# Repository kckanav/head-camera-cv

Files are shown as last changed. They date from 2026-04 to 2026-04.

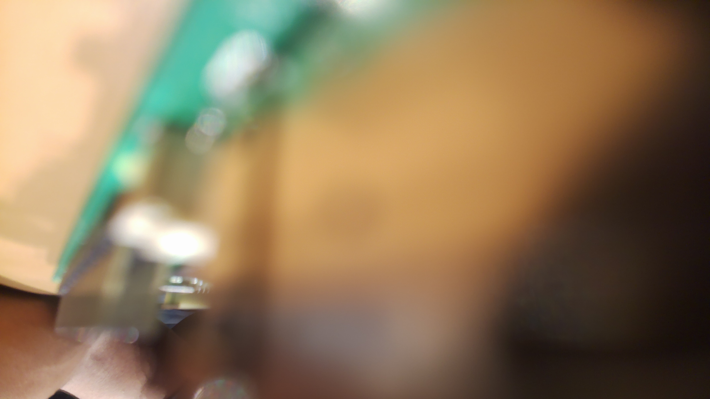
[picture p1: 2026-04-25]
inputs/23rd April 2026 - early test cam1.jpg

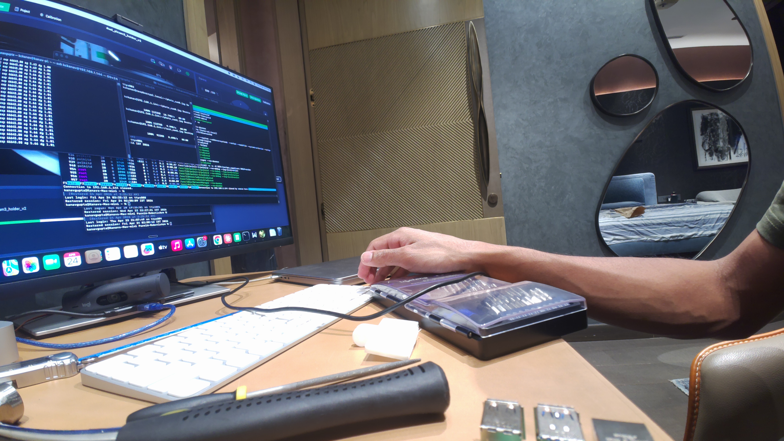
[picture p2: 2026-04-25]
inputs/24th April 2026 - photo cam1.jpg

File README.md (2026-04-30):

# Egocentric hand-and-object tracking on a head-mounted dual Pi Cam rig

## What we're building

A wearable computer-vision pipeline that captures the wearer's hands from their
own point of view and analyses **how they interact with objects** — finger
positions, arm pose, grip events, object orientation, and (eventually) the full
3D geometry of the interaction. Pure viewing first, neural-network analysis
later.

The key design choice is having **two cameras** instead of one. A single
egocentric camera can detect hands but has to *guess* depth from a flat image;
two cameras let us *measure* depth by triangulation. Most published egocentric
methods are monocular and have to work around that — we won't have to.

## Hardware

- 2× **Raspberry Pi Camera Module 3** (IMX708 sensor, 12 MP) mounted on a
  custom 3D-printed head bracket, tilted downward toward the wearer's hands.
- **Designed 24° toe-out** between the cameras (12° per side off-centre).
  Stereo calibration **recovered 18.9°** — print tolerances on the bracket.
  All math now uses the calibrated value, not the design value.
- **Recovered baseline**: 41.1 mm camera separation.
- **Raspberry Pi 5** for capture. Two sensor modes are exposed by the
  live-preview UI (`scripts/pi/dualstream.py`); both record at **1280×720
  H.264 at a hard-locked 30 fps**:
  - **2304×1296 binned full-FOV mode** — ~100° HFOV. **Current default**
    for the wide-FOV captures used by the WiLoR pipeline. Sensor caps at
    ~56 fps so 30 fps is comfortable.
  - **1536×864 centre-cropped mode** — ~75° HFOV. Older default; still
    used for the narrow-FOV reference clips and calibration.
  The 4608×2592 full-resolution mode is also offered by the UI but caps
  at ~14 fps so it can't sustain 30 fps recording — not used.
- Switching sensor mode changes intrinsics, so a fresh calibration is
  required after any switch. We keep both narrow-FOV (`""`) and wide-FOV
  (`" wide"`) calibrations side-by-side in `outputs/`.
- CAD source in `cad/dual_picam3_holder.scad`; v2 STL/3MF is the current revision.

## Pipeline plan (staged ladder)

The plan is to grow capability one stage at a time, validating each on real
footage before adding the next. Stages are roughly in order of "what unlocks
the most when you do it next":

| # | Stage | Purpose | Status |
|---|---|---|---|
| 1 | Per-camera hand keypoints (MediaPipe) | Prove fingers are trackable on real footage | **Done** |
| 2 | Arm / body pose | Wrist-elbow-shoulder context | Not started |
| 3 | Stereo calibration + rectification | Unlock metric depth for everything below | **Done** |
| 4 | Sparse 3D fingertip triangulation | Per-finger positions in centimetres | **Done** |
| 5 | Object segmentation / tracking (SAM 2) | Know which pixels belong to the object | **Next** |
| 6 | Grip event detection (heuristic first) | "Is the hand currently holding it?" | Not started |
| 7 | Object 6-DoF pose | Orientation, not just position | Optional / later |
| 8 | Dexterous hand capture (WiLoR + stereo) | Full MANO mesh + joint angles, robot-retargeting-ready | **In progress** — Phases 0-3 done, canonical pipeline at `scripts/pipeline/08_wilor_canonical.py`. Phase 4 (table-frame anchoring) and 5 (robot-training export) are next. See [PLAN.md](PLAN.md). |

## What we've achieved so far

### Stitching pipeline (`scripts/viz/stitch_panorama.py`)

Earlier the goal was to combine the two camera streams into one image. Started
as a Colab snippet (Lowe-less SIFT, Colab-only display, wrong-direction
homography); rewrote it to run locally with Lowe's ratio test, RANSAC, and
correct canvas math.

A homography is estimated **once** from a representative mid-clip frame and
reused for every frame — the cameras are rigidly mounted, so per-frame
estimation would be wasted compute. Output: `outputs/<date> - stitched
panorama.mp4` (~300 MB, gitignored; sample frame committed).

Important finding: **stitching is the wrong tool for our actual goal**.
A homography collapses both views onto a single plane, which destroys exactly
the parallax that gives depth perception. The panorama is useful as a quick
debug view, but for the real pipeline we want the two views *preserved*, not
fused. This is what motivates the stereo-calibration step over a fancier
stitcher.

### Hand detection sanity check (`scripts/pipeline/01_per_cam_sanity.py`)

Ran **MediaPipe HandLandmarker (Tasks API)** on a 15-second clip from each
camera (`1:40 – 1:55` of the 4-minute test recording).

Results on `25th April 2026` test clips:

| Camera | Frames | Hand-detected | Rate |
|---|---|---|---|
| cam0 | 451 | 449 | **99.6 %** |
| cam1 | 451 | 420 | **93.1 %** |

Inference runs at ~37 fps on M2 CPU — comfortably faster than real-time, so it
should work on the Pi 5 too.

#### Observations from the annotated outputs

- **Drop rate is ~2–3 % overall**, concentrated in moments where the hand is
  partially out of frame or only a few fingers (e.g. thumb + index + middle)
  are visible. The detector seems to either drop the hand or hallucinate a
  plausible-but-wrong skeleton in those frames. This is the expected failure
  mode for any 2D keypoint detector on partial views, and is one of the things
  stereo + 3D will help with.
- **Strong success case**: when the hand is wholly visible — even with heavy
  inter-finger occlusion (both hands gripping a tube of grease, fingers wrapped
  around) — keypoints stay locked at 0.94–0.99 confidence on both cameras.

### Stereo calibration (`scripts/calibration/make_charuco_board.py`, `scripts/calibration/calibrate_stereo.py`)

Stage 3 needed two pieces:

**1. A calibration target.** `make_charuco_board.py` generates a 9×6
ChArUco board PDF (30 mm squares, 22 mm 5×5 ArUco markers, A4 landscape @
600 DPI) with a 100 mm scale bar in the margin to verify print scale with a
ruler.

**2. The calibration itself.** `calibrate_stereo.py` takes synchronised left/right
videos of the board moved by hand in front of a tripod-mounted rig (~40 s of
footage at 30 fps), then:

- Samples one frame pair every 0.5 s (~80 pairs).
- Detects ChArUco corners independently in each view.
- Per-camera intrinsics with `cv2.calibrateCamera`.
- Stereo extrinsics with `cv2.stereoCalibrate(..., CALIB_FIX_INTRINSIC)`.
- Rectification with `cv2.stereoRectify(..., alpha=1)`. `alpha=1` preserves
  the full source FOV (with black padding where rectification has no source
  pixel) — important on this rig because hands frequently sit near the top
  edge of the frame; the more-aggressive `alpha=0` cropped them off.
- Saves intrinsics, extrinsics, rectification rotations, projection matrices,
  `Q`, and `cv2.remap` lookup tables to `outputs/<date> - stereo
  calibration.npz`. Renders a side-by-side rectified sample with green
  scanlines as a visual check (corresponding points must lie on the same
  scanline).

Result on `27th April 2026` calibration capture (71/79 usable pairs):

| Metric | Result | Bar |
|---|---|---|
| cam1 intrinsic rms | 0.24 px | < 0.5 = good |
| cam0 intrinsic rms | 0.27 px | < 0.5 = good |
| Stereo rms | 0.26 px | < 1.0 = good |
| Recovered toe-out | **18.9°** | designed 24° |
| Recovered baseline | **41.1 mm** | matches the bracket |
| Recovered focal length | fx ≈ 803 px | matches Pi Cam 3 ~75° HFOV |

Calibration is well below the conservative quality threshold; the rectified
sanity image (`outputs/<date> - rectified pair sanity.jpg`) confirms scanline
alignment across both views.

Implied **depth precision** at hand-interaction range (`ΔZ = Z² · Δd / (f · B)`,
½-px matching):

| Distance | Disparity | Depth precision |
|---|---|---|
| 30 cm | 110 px | ~1.4 mm |
| 50 cm | 66 px | ~3.8 mm |
| 80 cm | 41 px | ~10 mm |

Single-digit-millimetre depth resolution at hand-interaction range — plenty
for grip aperture, fingertip positions, and "is the hand touching the object"
heuristics.

### Sparse 3D hand triangulation (`scripts/pipeline/04_triangulate_mp.py`, `scripts/viz/inspect_3d_mp.py`)

Stage 4 puts everything together:

1. Load the stereo calibration `.npz`.
2. Rectify each frame pair with the precomputed `cv2.remap` tables.
3. Run MediaPipe HandLandmarker independently on each rectified view.
4. Pair left/right hand detections by **wrist-row proximity** — after
   rectification the epipolar constraint is "same image row", so a true
   match must agree in y. ±18 px tolerance.
5. Triangulate the 21 landmarks per paired hand with
   `cv2.triangulatePoints(P1, P2, ...)` → 3D positions in metres in the
   left-rectified camera frame.
6. **Sanity-filter** any pair whose triangulated wrist Z falls outside
   `[10 cm, 200 cm]` — catches wrong-hand pairings the row check lets through.
7. Sort hand slots by left-view wrist X for frame-to-frame stability.
8. Save per-frame `(N_frames, 2, 21, 3)` 3D landmarks (NaN-padded) to
   `outputs/<date> - stereo hand 3d.npz`.
9. Write a side-by-side rectified video annotated with skeletons, wrist
   depth (cm), and pinch (thumb-index) aperture (mm).

`inspect_3d_mp.py` is a small companion that loads the npz and plots wrist
depth and pinch over time, one curve per hand slot.

Result on the first 60 s of the test recording (alpha=1 rectification):

| Metric | Result |
|---|---|
| Hands detected (cam1) | 1689 / 1801 = 94 % |
| Hands detected (cam0) | 1582 / 1801 = 88 % |
| Stereo-paired (after Z filter) | 1100 / 1801 = 61 % |
| Median wrist depth | 33.3 cm |
| Wrist depth 5–95 pct | 21.6 – 47.0 cm |
| Median pinch aperture | 36 mm |
| Inference rate | ~19 fps on M2 CPU (two MediaPipe instances) |

The 5–95 percentile wrist-depth band lies entirely within the expected
hand-interaction range. The trajectory plot shows clean steady-state
clustering at ~32 cm during periods of close manipulation, with both hands
tracked simultaneously.

**Known residual issue.** A single fingertip can occasionally triangulate
to a wildly wrong Z even when the wrist is solid — MediaPipe's per-finger
keypoints are noisier than the wrist, and a 1 px disparity error at that
landmark gives a large depth error. Visible as occasional pinch outliers
> 150 mm in the trajectory plot. Per-landmark Z-clamping or short-window
temporal smoothing would clean it up. Not blocking.

### Stage 8 in progress — WiLoR + stereo dexterous hand pipeline (`scripts/pipeline/08_wilor_canonical.py`)

The sparse 21-keypoint MediaPipe output is enough for *trajectories* but not
for retargeting to arbitrary robot grippers. To capture data that can drive
a parallel-jaw, 3-finger, or anthropomorphic robot hand from the same
recording, we moved to **WiLoR** ([CVPR 2025](https://github.com/rolpotamias/WiLoR)) —
an end-to-end ViT model that produces full **MANO** parameters (16 joint
rotations + 778-vertex mesh) per hand. Stereo gives us an unusual
advantage: WiLoR is monocular and has scale ambiguity, but our calibrated
stereo can fix the scale precisely.

Phases 0–3 are all done:

- **Phase 0–1** (env + sanity): WiLoR runs on Apple MPS on this M2 host
  (with the YOLO detector on CPU per ultralytics issue #4031). Sanity
  check on a real Pi-Cam frame: hand detected, mesh extent ~16 cm, 2D
  keypoints overlay cleanly on the actual hand.
  Entry point: `scripts/experiments/wilor_sanity.py`.
- **Phase 2** (per-view WiLoR + stereo wrist triangulation): metric wrist
  depth annotations on a side-by-side video. Median wrist depth ~34 cm,
  in line with what MediaPipe-stereo reported on similar footage
  (regression baseline holds).
  Entry point: `scripts/experiments/wilor_wrist_stereo.py`.
- **Phase 3 (full Umeyama)** — *reference experiment*: triangulate all 21
  keypoints, fit a 7-DOF similarity transform, project the same world-
  frame mesh into both views. 99.3% fuse rate, but median 2D reprojection
  error blew up to 10 px. **Worse than monocular WiLoR.** Kept for the
  negative-result record.
  Entry point: `scripts/experiments/wilor_phase3_umeyama.py`.
- **Phase 3 (anchored)** — *canonical pipeline*: per view, `cv2.solvePnP`
  fits 6-DOF pose to WiLoR's 2D keypoints; stereo wrist depth supplies
  a 1-DOF metric scale anchor `k = Z_stereo / t_pnp[2]`. Uniform 3D
  scaling preserves perspective 2D projection (`(X,Y,Z) → (fX/Z, fY/Z)`
  is invariant under `(kX, kY, kZ)`), so the rendered overlay matches
  the per-view monocular baseline (median PnP residual ~2 px) while
  the underlying mesh is metric. The scale anchor uses stereo only for
  the one thing it can give that monocular cannot.
  Entry point: `scripts/pipeline/08_wilor_canonical.py`. Has full
  CUDA/MPS device portability via `scripts/_lib/device.py` plus a
  `--bench` flag for per-stage perf tracing.

Discovered and fixed along the way:

- **Left-hand keypoint mirroring**: WiLoR's `ViTDetDataset` flips left-hand
  input crops, so `pred_keypoints_2d` and `pred_vertices` come out in
  flipped-crop coords. Multiplying X by −1 before mapping back to image
  coords fixes anatomically-flipped renders.
- **Centralised WiLoR runtime workarounds** in `scripts/_lib/wilor_setup.py`:
  pyrender stub (no EGL on macOS), `torch.load weights_only=False` patch
  (PyTorch 2.6 broke YOLO ckpt loading), and the wilor sys.path / chdir
  setup. Every wilor script now has a single `import wilor_setup` line
  instead of 60+ lines of boilerplate.

Full plan, install gotchas, and Phases 4–5 (visualisation + table-frame
robot-training export) are in [`PLAN.md`](PLAN.md).

### Other known limitations

- **Handedness labels are unreliable** on egocentric video. MediaPipe was
  trained primarily on selfie/forward-facing data, so its `Left` / `Right`
  classification can flip on top-down head-mount input. The keypoint
  *positions* themselves are fine; we side-step handedness by pairing hands
  across views via the rectified-row epipolar constraint instead. Cheap fix
  if we ever need it: relabel based on which side of the frame the wrist
  sits on. Proper fix: swap in **HaMeR** or **WiLoR** (both trained on
  egocentric datasets like Ego4D and EPIC-Kitchens) — that's stage 8.
- **Parallax artefacts in the stitched panorama** — close-foreground hands
  sit at a different depth than background and can't be aligned by a single
  planar homography. Inherent to the geometry, not a bug. Going away
  because we're not stitching anymore — the calibrated stereo pipeline
  preserves both views.

## Repo layout

```
README.md / PLAN.md / CLAUDE.md   Docs (read CLAUDE.md before contributing).

scripts/                          All pipeline entry points (run from repo root).
  _lib/                           Shared imports (sys.path-injected by each script).
    dated.py                      today_pretty() helper.
    device.py                     pick_device / configure_perf — CUDA/MPS/CPU portability.
    wilor_setup.py                pyrender stubs, torch.load patch, wilor sys.path/chdir.
  pi/
    dualstream.py                 Pi-side dual capture + live HTML preview UI.
  calibration/
    make_charuco_board.py         ChArUco PDF generator (stereo calibration target).
    make_aruco_marker.py          ArUco PDF generator (table-frame anchor for stage 8 phase 4-5).
    calibrate_stereo.py           Stereo calibration from board videos (stage 3).
  pipeline/                       The canonical pipeline, in run order.
    01_per_cam_sanity.py          MediaPipe HandLandmarker per-camera sanity (stage 1).
    04_triangulate_mp.py          Sparse 3D hand triangulation via MediaPipe + stereo (stage 4).
    08_wilor_canonical.py         WiLoR + stereo metric depth (stage 8). --bench for perf trace.
  viz/                            Visualisation + debug viewers.
    play_stereo.py                SBS rectified playback with on-the-fly --alpha.
    depth_dense.py                Dense stereo depth (overlay / turbo / both).
    inspect_3d_mp.py              Trajectory plot of triangulated MediaPipe hand data.
    stitch_panorama.py            Old SIFT/RANSAC panorama stitcher (debug-only).
    wilor_ar_monocular.py         Per-view monocular AR overlay (visual baseline).
  experiments/                    Reference scripts kept for the record.
    wilor_sanity.py               Single-image WiLoR sanity check (stage 8 phase 1).
    wilor_wrist_stereo.py         Per-view WiLoR + stereo wrist-only triangulation (phase 2).
    wilor_phase3_umeyama.py       Phase 3 (full Umeyama) — superseded; kept as negative-result record.

cad/                              Head-mount CAD (.scad source + .stl / .3mf exports).
inputs/                           Tracked test material — filenames dated by capture.
outputs/                          Tracked generated artefacts — filenames dated by generation.

raw/                              (gitignored) Raw camera mp4 + h264 streams from the Pi.
models/                           (gitignored) Re-downloadable model weights (e.g. hand_landmarker.task).
wilor/                            (gitignored) Cloned WiLoR repo — large weights, separate license.
.venv/                            (gitignored) Python 3.9 venv for stages 1-4.
.venv-hamer/                      (gitignored) Python 3.10 venv for stage 8.
```

Run scripts from the repo root so the relative paths in `inputs/` /
`outputs/` / `models/` resolve correctly:
`.venv/bin/python scripts/calibration/calibrate_stereo.py` or
`.venv-hamer/bin/python scripts/pipeline/08_wilor_canonical.py`.

Filenames in `inputs/` and `outputs/` look like `27th April 2026 - stereo
hands annotated.mp4`. Re-running a script on a new day produces a new
dated artefact rather than overwriting yesterday's, so progress is visually
browsable from `ls outputs/`.

**Not in git** (over GitHub's 100 MB limit, redownloadable, or
license-restricted; kept locally only): everything in `raw/`, `models/`,
`wilor/`, and the full stitched panorama / 60-s WiLoR demo renders in
`outputs/`. Switch to **git-lfs** if any of these need to be tracked.

## What's next

Stages 3 and 4 are done — we now have calibrated stereo and a working sparse
3D hand pipeline. Two reasonable directions:

**Stage 5 — object segmentation (SAM 2).** Identify which pixels belong to
the held object so we can ask "which finger is touching what part of it?".
Combines naturally with the existing 3D hand keypoints to produce per-frame
hand–object contact features.

**Refine stage 4.** Per-landmark Z-clamping and short-window temporal
smoothing to clean up the fingertip outliers; identity tracking so hand
slots stay consistent when hands physically cross; running MediaPipe on the
*raw* frames and projecting the keypoints through the rectification map
afterward, to claw back the small detection-rate gap from running on
rectified frames.

## Commit history (running log)

- `c9810b2` — initial object detection from both different cameras
- `5301032` — organise repo into inputs/ and outputs/ with readable dated filenames
- `02fef54` — README summarising goals, architecture, status, and next step
- `e63edb9` — hand detection on first minute of each camera
- `e008189` — generate ChArUco calibration board sized for the Pi Cam 3 rig
- `fa40c85` — stereo calibration (stage 3): script, capture footage, recovered geometry
- `402af8c` — sparse 3D hand triangulation (st	age 4): pipeline, results, trajectory plot
- `19c7ecd` — README + CLAUDE.md update for stages 3 and 4
- `9f17555` — stage 8 phase 0+1 (WiLoR setup + sanity)
- `5254d62` — stage 8 phase 2 + minimal phase 3 (per-view WiLoR + stereo wrist triangulation, with left-hand mirror bug fix)
- `d22400f` — stage 8 wide-FOV: dualstream sensor-mode UI, recalibration, demo CLI args, 60-s perf trace
- `582a596` — restructure root into scripts/ + cad/ + raw/ + models/ for navigability

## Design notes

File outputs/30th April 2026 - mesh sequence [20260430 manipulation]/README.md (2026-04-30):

# Mesh sequence — 20260430 manipulation

Generated by `scripts/viz/export_obj_sequence.py` from
`30th April 2026 - dataset [20260430 manipulation].npz`.

## Contents

- `scene.obj` — static helper: 1 m × 1 m table plane at Z=0, plus a 8 cm
  marker outline at the origin. Import once for visual context.
- `mesh_NNNN.obj` (542 frames at 30.0 fps, ~18.1 s) — per-frame
  hand meshes. Each file contains up to two named objects:
  `hand_slot0` (the leftmost-by-X hand in the source video) and `hand_slot1`.
  Frames where a hand wasn't tracked simply omit that object.

Hand meshes follow MANO topology: 778 vertices, 1538 triangles per hand.

## Coordinate frame

**Table frame, metric metres.** (0, 0, 0) is the marker centre on the
table. +Z is up from the table surface. Set your DCC tool's scene units
to metres.

## Open in Blender

### Easiest — Stop Motion OBJ addon

1. Install the [Stop Motion OBJ](https://github.com/neverhood311/Stop-motion-OBJ)
   addon (free, in the Blender extension menu or downloadable from GitHub).
2. File → Import → Mesh Sequence...
3. Point at this directory, set the file pattern to `mesh_*.obj`, and
   set the playback frame rate to **30 fps**.
4. Import `scene.obj` separately (File → Import → Wavefront (.obj)) for
   the table + marker reference.

### Manual via Python (no addon)

Paste into Blender's Python console:

```python
import bpy
from pathlib import Path

seq_dir = Path("/absolute/path/to/this/directory")
for f in sorted(seq_dir.glob("mesh_*.obj")):
    bpy.ops.wm.obj_import(filepath=str(f))

# Then keyframe visibility per frame manually, or animate via the
# Mesh Cache modifier on a base mesh.
```

## Animation timing

Frame `mesh_NNNN.obj` corresponds to time `NNNN / 30` seconds since the
start of the source clip.

Set the scene render fps to **30** to play back at real-time speed.

## What's where

The hand meshes are oriented anatomically: looking down at the table
from above, with +Z pointing up at the camera. The marker on the table
is at (0, 0, 0). Hand positions on the table appear in the +X / +Y
plane (approximately; the marker's chirality defines the +X axis of the
table).

This is the **K-anchored metric mesh** from the canonical pipeline —
positions are stereo-correct (the wrist is metric), but the mesh size is
uniformly scaled by the per-frame `k ≈ 0.78` factor so the wrist matches
stereo. To get the WiLoR-monocular-sized mesh instead (slightly larger),
rebuild from `mano_pose` + `mano_betas` in the parent `.npz` via the
MANO model, then translate by `wrist_table[i, slot]`.

## Provenance

- `schema_version`: 1.0
- `source_canonical`: 30th April 2026 - phase3 anchored fused [20260430 manipulation].npz
- `source_anchor`: 30th April 2026 - table anchor [20260430 manipulation].npz
- `source_calibration`: 30th April 2026 wide - stereo calibration.npz
- `generated_on`: 30th April 2026

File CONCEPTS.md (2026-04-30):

# Pipeline concepts (Q&A)

Notes on **how** and **why** the egocentric hand-tracking pipeline works,
captured from a series of explainer questions during development. Read this
if you want to understand the conceptual framework — what each model does,
what units and frames the data lives in, and why the pipeline is structured
the way it is.

For **what** the scripts do, see [`CLAUDE.md`](CLAUDE.md).
For **what's planned**, see [`PLAN.md`](PLAN.md).
For the **project narrative + ladder**, see [`README.md`](README.md).

---

## Contents

1. [What CV models are we using? (full data flow + math)](#1-what-cv-models-are-we-using)
2. [What creates the blue-glove effect?](#2-what-creates-the-blue-glove-effect)
3. [MANO vs WiLoR — what is the difference?](#3-mano-vs-wilor--what-is-the-difference)
4. [How are θ and β stored, and in what reference frame?](#4-how-are-θ-and-β-stored-and-in-what-reference-frame)
5. [What is the ArUco marker for?](#5-what-is-the-aruco-marker-for)
6. [Why don't we just triangulate the table directly?](#6-why-dont-we-just-triangulate-the-table-directly)

---

## 1. What CV models are we using?

Three deep-learned models, plus a stack of OpenCV geometry. None of the
deep-learned ones live inside this repo — they're either downloaded
checkpoints or installed packages.

### The deep-learned models

**YOLOv8 hand detector** (`wilor/pretrained_models/detector.pt`)
- Input: full RGB frame.
- Output: 2D bounding boxes of hands + handedness label (left/right).
- Math: standard one-stage anchor-free detector. CNN backbone → per-pixel
  bbox + class.

**WiLoR ViT** (`wilor/pretrained_models/wilor_final.ckpt`)
- Input: a 256×256 hand crop from YOLO's bbox.
- Output: MANO pose θ (16 axis-angle joint rotations), shape β (10
  betas), per-image weak-perspective camera, plus reprojected 2D / 3D
  keypoints and the 778-vertex mesh.
- Math: ViT encoder → transformer decoder → regression heads. Trained on a
  mix of monocular hand datasets. The output is **monocular and
  scale-ambiguous** — pose and *relative* shape are right, but absolute
  size is a guess.

**MANO** (`wilor/mano_data/MANO_RIGHT.pkl`)
- Not a learned step at runtime — a fixed parametric hand model.
- Input: pose θ + shape β.
- Output: 778-vertex mesh + 21 joint positions.
- Math: linear blend skinning on a mean template mesh, plus pose-dependent
  blend shapes. Closed form, fast.

### OpenCV geometry (no deep learning, just math)

**ArUco / ChArUco detectors** — `cv2.aruco.ArucoDetector` finds quadrilateral
fiducials and returns their 4 corners with sub-pixel precision. Used for
calibration (ChArUco board) and table anchoring (single ArUco marker).

**Stereo calibration suite** (one-time, captured in our `.npz`):
- `cv2.calibrateCamera` → intrinsics K (focal length, principal point) and
  distortion coefficients per camera.
- `cv2.stereoCalibrate` → extrinsic R, T relating the two cameras:
  `X_right = R · X_left + T`.
- `cv2.stereoRectify` → rectification rotations R1, R2 + projection
  matrices P1, P2 such that, after virtually rotating each camera by
  R1/R2, corresponding image points lie on the same row.

**Stereo triangulation** — `cv2.triangulatePoints(P1, P2, x_l, x_r)` solves
for 3D X such that both rectified projections match. After rectification:
`Z = fx · baseline / (x_l − x_r)`.

**PnP** — `cv2.solvePnP` / `solvePnPGeneric`. Given 3D object points in
some local frame and their 2D image projections, recover the camera pose
`(R, t)` such that `K · (R · X_local + t)` projects to the observed 2D.
We use SQPNP for hand keypoints and IPPE_SQUARE for the marker.

**MediaPipe HandLandmarker** (legacy, only in
`scripts/pipeline/04_triangulate_mp.py`) — fast 21-keypoint detector kept
as a regression baseline against WiLoR.

### Data flow per frame

```
                                    ┌──── cam1 RAW frame (left) ────┐
                                    │                               │
[1] YOLO ──► hand bboxes  ─────────►│                               │
                                    │                               │
[2] WiLoR ViT (per crop) ──► θ, β, kp_3d_local, kp_2d_full, vertices│
                                    │                               │
[3] MANO (θ, β) ──► 778-vertex mesh in MANO local frame             │
                                    │                               │
                                    │       ┌──── cam0 RAW frame (right) ───┐
                                    │       │                                │
[1+2+3] same pipeline on right view │       │   another (R_right, t_right)   │
                                    │       │                                │
                                    ▼       ▼                                │
                          ┌────────────────────────────────────┐             │
[6] Triangulate wrist:    │ wrist 2D in cam1 + wrist 2D in cam0│             │
    rectify both, then    │ ──► cv2.triangulatePoints          │             │
    triangulate           │ ──► metric Z_wrist in WORLD frame  │             │
                          └────────────────────────────────────┘             │
                                       │                                     │
                                       ▼                                     │
[7] solvePnP(SQPNP) per view: fit (R_view, t_view) so monocular mesh         │
    projects to WiLoR's 2D keypoints. t_view[2] = monocular wrist depth.     │
                                       │                                     │
                                       ▼                                     │
[8] Scale anchor: k = Z_stereo_wrist / t_view[2]   (1 DOF per view)          │
                                       │                                     │
                                       ▼                                     │
[9] Metric mesh in cam frame: k · (R_view · vertices_local + t_view)         │
                                       │                                     │
                          ┌────────────┴───────────┐                         │
                          │                        │                         │
                   ┌──────▼─────┐         ┌────────▼──────┐                  │
                   │ project to │         │ transform via │                  │
                   │ each view  │         │ R1.T into     │                  │
                   │ (render)   │         │ WORLD frame   │                  │
                   └────────────┘         │  (stored)     │                  │
                                          └───────────────┘                  │

    ┌────────────────────────────────────────────────────────────────────────┘
    │  Separately:
    │  [4] ArUco detector finds marker corners in each view
    │  [7] solvePnP(IPPE_SQUARE) → marker pose (R_l, t_l) per view
    │  ──► T_world_to_table per frame (transforms WORLD frame → TABLE frame)
    │
    ▼
For Phase 5 export: apply T_world_to_table to all stored 3D quantities,
producing table-anchored, metric, retargeting-ready demonstrations.
```

### The two non-obvious tricks

**Trick 1 — Uniform 3D scaling preserves perspective 2D.** A point at
`(X, Y, Z)` projects to `(fX/Z, fY/Z)`. Scale the *whole 3D point* to
`(kX, kY, kZ)` and the projection is `(fkX/kZ, fkY/kZ)` = unchanged. So we
can change the metric size of the monocular mesh without breaking its 2D
fit. That's why a **1-DOF stereo correction** (just absolute scale) is
enough — pose, rotation, and finger-shape are all preserved from monocular.

**Trick 2 — Disparity → depth.** After rectification, the only thing that
varies for a 3D point is its horizontal pixel position between the two
views. The relationship is exactly `Z = fx · baseline / disparity`. So
with calibrated `fx ≈ 545 px` and `baseline = 41.9 mm`, every pixel of
disparity error at 50 cm depth costs ~1 cm in Z. That's the noise floor
we live with on this rig.

---

## 2. What creates the blue-glove effect?

The blue glove is the rendered **MANO mesh** painted onto the original
frame in 2D, with shading. Five steps:

**1. Mesh geometry — what we render.** MANO gives us 778 vertices and 1538
triangular faces forming a hand. WiLoR predicts the per-frame mesh; the
canonical pipeline scales it to metric size via the `k` anchor.

**2. Project 3D vertices to 2D.** `cv2.projectPoints(vertices_3d_camera,
K, dist)` gives us the 2D pixel coordinates for each of the 778 vertices
in the image plane. Now each triangle has both a 3D position (in camera
frame) and a 2D footprint.

**3. Paint the triangles back-to-front.** This is the **painter's
algorithm** — we sort all 1538 triangles by their **mean 3D Z** (depth),
descending, and draw the farther ones first so nearer ones overpaint
them. No z-buffer, no GPU — just sort and fill in order.

```python
face_z = triangles_3d.mean(axis=1)[:, 2]
order = np.argsort(-face_z)           # back to front
for fi in order:
    cv2.fillConvexPoly(overlay, pts2[fi], color)
```

**4. Per-triangle shading — Lambertian blue.** This is what gives it the
3D look instead of being a flat blob. For each triangle:
- Compute its 3D normal: `n = (v1 − v0) × (v2 − v0)`, normalised.
- Compute brightness:
  `shade = max(|n · light_direction|, 0.3)`.
  We use a fixed light direction `(0, −0.4, −1)` (slightly above and
  behind the camera) and clamp to 0.3 minimum so back-facing triangles
  aren't fully black.
- Multiply the base BGR colour `(255, 110, 30)` by `shade`. That base
  is the saturated cyan-blue you see.
- Draw the triangle's edge with a slightly darker BGR `(220, 80, 20)`.
  That gives the polygonal "wireframe-on-skin" look.

**5. Alpha-blend onto the original frame.**

```python
out = cv2.addWeighted(overlay, 0.55, original_frame, 0.45, 0)
```

55% mesh-colour, 45% original. That's why the hand still shows through
faintly — the glove is translucent rather than opaque.

### Why it looks "right"

Because the underlying mesh is positioned to **match WiLoR's 2D keypoints
exactly** (uniform-scaling preserves 2D projection — Trick 1 above). So
when WiLoR locks the wrist and finger positions to the actual hand pixels,
the mesh you paint over the frame is registered to within ~2 px of the
real hand outline. Combined with depth-sorted shading, your eye reads it
as a 3D blue glove sitting on the hand instead of a flat overlay.

Pure NumPy + OpenCV — no GPU rendering. ~15 ms per frame on Apple MPS
for one hand.

---

## 3. MANO vs WiLoR — what is the difference?

The short version: **MANO is a *mathematical model* of a hand. WiLoR is a
*neural network* that estimates the parameters of that model from an
image.** They live at completely different levels of the stack — one is
geometry, one is perception.

### MANO — the hand "puppet"

MANO was published by the Max Planck Institute in 2017. It's a fixed
mathematical formula that describes how a hand looks and articulates.
Think of it as a rigged 3D hand model in Blender — fixed mesh topology
and fixed skeleton. You give it inputs and it gives you a 3D mesh.

Inputs:
- **θ** (theta): 16 joints × 3 axis-angle values = 48 numbers describing
  the joint rotations (wrist, knuckles, finger curls).
- **β** (beta): 10 shape coefficients describing the *person*'s hand
  (size, finger thickness, etc.). These don't change frame-to-frame for
  the same person.

Output (deterministic, computed by a closed-form function):
- A **778-vertex mesh** (the surface).
- **21 keypoints** (anatomical landmarks: wrist, MCPs, PIPs, DIPs,
  fingertips).

That's it. MANO is the puppet — it can take any pose, but it doesn't
know how to look at the world. It's frozen on disk as `MANO_RIGHT.pkl`.

### WiLoR — the "puppeteer"

WiLoR is a neural network (a Vision Transformer) trained on lots of hand
images. Its job is to look at a hand crop and **predict θ and β** —
i.e., decide what pose the MANO puppet should be in to match the image.

- Input: a 256×256 RGB hand crop.
- Output: predicted θ and β (plus a few extras like a per-image
  weak-perspective camera).

WiLoR by itself doesn't produce a mesh — it produces *parameters*. The
mesh comes out only when you plug those parameters into MANO's formula.

### How they work together

```
   image ─► [WiLoR network] ─► θ, β ─► [MANO formula] ─► 778-vertex mesh + 21 joints
            (perception)              (geometry)
```

Inside WiLoR's checkpoint there's actually a copy of MANO baked in, so
calling `model(batch)` runs both steps in one forward pass and gives you
`pred_vertices`, `pred_keypoints_3d`, etc. directly. But conceptually
they're separate.

### What this means for our pipeline specifically

- **The skeleton drawn on the AR video** = the 21 keypoints. The
  *anatomy* (which dot is the wrist, which is the index-MCP, etc.) is
  **defined by MANO**. Their *positions in the image* come from
  **WiLoR's predictions**.
- **The blue-glove mesh** = the 778-vertex surface. The *topology*
  (which vertex connects to which) is **MANO**. Their *3D positions*
  come from **WiLoR + MANO**.

In the saved `.npz`, the most compact and most "lingua franca" thing to
keep is **θ and β**. With those, anyone can rebuild the mesh later by
calling MANO. Mesh vertices are 778 × 3 = 2334 floats per hand per frame;
θ + β is just 48 + 10 = 58 floats. Most robot-retargeting codebases
consume θ directly — they map MANO's joint angles onto their robot's
joint angles.

### Why the distinction matters

It means we have a **swappable perception layer**. If WiLoR ever becomes
obsolete (or HaMeR works better on egocentric video, or some new model
lands later), we can swap the predictor without changing anything
downstream — as long as the new model also outputs MANO parameters, all
our anchoring math, our table-frame export, our retargeting code keeps
working.

That's why our Phase 5 export should save `mano_pose` (= θ) and
`mano_betas` (= β) — not just the meshes. The meshes are derived; θ + β
are the *source of truth*.

---

## 4. How are θ and β stored, and in what reference frame?

### θ — joint rotations

Stored as a `(16, 3)` float array. **48 numbers.**

Each row is an **axis-angle vector**: a 3D vector where the *direction*
is the rotation axis and the *magnitude* (in **radians**) is the
rotation angle. So if `θ[5] = (0, 0, 1.57)`, that means "joint 5 rotates
1.57 radians (= 90°) around the +Z axis of its parent joint's frame."

There are 16 joints in MANO's tree: 1 wrist + 3 per finger × 5 fingers.
They're arranged hierarchically (wrist → MCP → PIP → DIP), so each
rotation is **relative to its parent**. The wrist's rotation is relative
to the MANO "root frame" — i.e., it tells you which way the whole hand
is facing in MANO's local universe.

Units: radians. Range: ~[−π, π] per axis.

### β — shape coefficients

Stored as a `(10,)` float array. **10 numbers.**

These are **PCA scores** in a learned basis of hand shapes. MANO was
built by scanning ~1000 real hands and running PCA on the variation. β
= (1.5, −0.3, 0.8, ...) means "this person's hand = mean hand + 1.5 ×
shape_basis_0 − 0.3 × shape_basis_1 + ...". The first component is
roughly overall size (big hand vs small hand); later ones capture
finger-length ratios, palm thickness, etc.

Units: dimensionless. Typical range: [−3, +3] (it's standardised).

### 3D vertex positions — units and frame

When MANO computes its mesh from (θ, β), the output is `(778, 3)`
floats. The units are **metres**. But — and this is the key — they're in
**MANO's local frame, not the camera frame, and not the world**.

What does that mean concretely?

- The wrist is at the origin `(0, 0, 0)` of MANO's local frame.
- The mesh extends roughly ±0.1 m around the wrist (a hand is ~10 cm
  across).
- The orientation is a "canonical hand orientation" defined by MANO —
  palm-down, fingers pointing along some axis.

So when you call `MANO(θ, β)` and look at vertex 100, you might get
something like `(0.04, −0.02, 0.07)` metres. That doesn't mean "vertex
100 is 4 cm to the right of the camera." It means "vertex 100 is 4 cm
in the +X direction from the wrist *in MANO's own coordinate system*,
when the hand is posed according to θ".

It's analogous to having a rigged 3D hand model in Blender: the mesh has
positions in the model's local space, but until you put it INTO a scene
with a transform, those positions don't correspond to any real-world
location.

### Why this matters for our pipeline

WiLoR outputs vertices in MANO's local frame. To **place that mesh in
your real scene** (above your table, anchored to the marker), we need
three additional pieces of information that MANO+WiLoR alone can't give
us:

1. **Where is the hand in 3D space?** (translation `t`)
2. **Which way is the hand facing in 3D space?** (rotation `R`)
3. **What's the absolute size?** (scale `k`)

Each of those is solved by a different step in the canonical pipeline:

| Question | Solved by | Math |
|---|---|---|
| Where in 3D? | `solvePnP` per view | Fit (R, t) so projected MANO 2D matches image 2D, plus stereo wrist for absolute Z |
| Which way facing? | Same `solvePnP` | The R part of (R, t) |
| Absolute size? | Stereo wrist depth + the `k` anchor | `k = Z_stereo_wrist / t_pnp[2]` |

Once you have (R, t, k), you transform every MANO vertex:

```
vertex_in_camera = k · (R · vertex_in_MANO_local + t)
```

Now the vertex has a 3D position in the camera's frame, in metric metres.

Then `T_world_to_table @ vertex_in_world` puts it in table frame.

So the **chain of frames** for a single vertex looks like:

```
MANO local frame (wrist-centred, MANO units)
    │  scale by k, rotate by R, translate by t   ← from solvePnP + stereo anchor
    ▼
Real left camera frame (metres, camera origin)
    │  apply R1 (stereo rectification)            ← from cv2.stereoRectify
    ▼
World frame (= rectified-left frame, metres)
    │  apply T_world_to_table                     ← from ArUco solvePnP
    ▼
Table frame (metres, marker centre = origin, Z = up)
```

That's why the saved `.npz` has so many fields — each is needed to
express where something is at a different stage of the chain.

### Pixels vs 3D positions

MANO outputs are **never** in pixels. Pixels show up only when you
*project* a 3D point through a camera intrinsic matrix `K`:

```
pixel = K · (3D point in camera frame)
```

That's the `cv2.projectPoints` step. It's the LAST thing that happens
in the canonical pipeline — only for the rendered visualisation.

For a Phase 5 export to a 3D modelling software, **you don't want pixels
at all**. You want the 3D vertex positions in **table frame, in metric
metres**. Or even more compact: you want θ + β + the wrist 6-DoF
transform that maps MANO local → table frame, which lets the consumer
rebuild everything else.

---

## 5. What is the ArUco marker for?

The marker is doing a **different job** than answering the three "where /
which-way / how-big" questions for the hand. Those three are answered
**entirely from the cameras**, not the marker:

- **Where the hand is in 3D space** → `solvePnP` per view + stereo
  triangulation of the wrist.
- **Which way the hand is facing** → `solvePnP` per view (the R part of
  the same fit).
- **Absolute size (the `k` anchor)** → stereo triangulation of the wrist
  2D landmark across both views, which gives metric Z, which lets us
  compute `k = Z_stereo / Z_monocular`.

None of these involve the marker. They use:
- The **stereo calibration** (the `.npz` from `calibrate_stereo.py`),
  which tells us the rigid geometry between the two cameras — that's
  what makes stereo triangulation possible at all.
- The **monocular WiLoR predictions** in each image.

So after this stage, we have a metric MANO mesh **in the moving
head-mounted camera's frame**, frame by frame.

### What the marker does — answers a different question

The marker answers: **"Where is the table?"**

Without the marker: your camera is on your head. As your head moves, the
camera frame moves with it. A point that's stationary on the table — say,
the corner of a coaster — has different camera-frame coordinates every
frame. If we just exported the hand mesh in camera frame, you'd see the
hand AND the entire world wobbling around in Blender as you replayed the
demo, because everything is being expressed relative to a moving camera.

For robot training, you want everything in **the robot's workspace** —
which is anchored to the table, not to the user's head. So we need a
transform that takes camera-frame points → table-frame points, **per
frame**, accounting for head motion.

The marker provides exactly this. Detected every frame, `solvePnP` against
its known size gives us `T_world_to_table[frame]` — a per-frame transform
from the moving world (rectified-left) frame into the stationary table
frame.

The marker doesn't help us figure out where the hand is. It helps us
**express** where the hand is, **relative to the stationary table** instead
of the moving camera.

### The two stereo roles, separated

There are actually **two completely separate uses of stereo** in our
pipeline, and it's worth keeping them distinct:

| Stereo role | Source | What it gives us |
|---|---|---|
| **Stereo calibration** (one-time, from the ChArUco board capture) | `<date> wide - stereo calibration.npz` | The rigid geometry between cam1 and cam0 (their R, T, intrinsics, distortion). This is what lets us triangulate ANY 2D-2D point pair into 3D. |
| **Stereo triangulation** (per frame, for the wrist) | Live, in `08_wilor_canonical.py` | The metric Z of the wrist, which anchors the absolute scale of the monocular MANO mesh via `k`. |

The marker is **separate from both of these**. It's a third role:

| Marker role | Source | What it gives us |
|---|---|---|
| **Table anchoring** (per frame) | Live, in `09_anchor_table.py` | A per-frame `T_world_to_table` transform that takes any camera-frame point and re-expresses it in stationary table coordinates. |

The full chain for a single hand vertex on a single frame is:

1. WiLoR predicts MANO θ, β → 778 vertices in **MANO local frame**
   (scale-free, wrist-centred).
2. `solvePnP` + stereo wrist triangulation → vertex in **left camera
   frame** (metric metres, but in a frame that moves with the head).
3. Stereo calibration's `R1` rotates left-camera into rectified-left =
   **world frame** (still moves with head, but parallel-rectified).
4. Marker-derived `T_world_to_table` → vertex in **table frame** (metric
   metres, stationary, Z=0 is the table surface).

The first three steps don't involve the marker at all. The marker only
enters at step 4.

---

## 6. Why don't we just triangulate the table directly?

You could absolutely triangulate the table. Two reasons we use a marker
anyway, both worth understanding.

### Reason 1 — Identifying the "same point" in both views

Stereo triangulation only works when you know that pixel `(x_l, y_l)`
in the left view and pixel `(x_r, y_r)` in the right view are **the
same physical point in 3D**. For the wrist, this is easy: WiLoR detects
"the wrist landmark" in each view independently, and we trust those two
detections refer to the same anatomical wrist.

For the table, what's the equivalent? The table is **mostly
featureless**. Most of its surface is flat colour with no texture. If you
tried to match pixels between the two views — say "this beige pixel in
the left view = which beige pixel in the right view?" — you'd have no
way to know. Every beige pixel looks like every other beige pixel. The
matching is ambiguous.

This is the classic **correspondence problem** in stereo vision. It's
why dense stereo (the `viz/depth_dense.py` script) gives crisp depth on
textured regions but noisy/missing depth on flat surfaces. If you ran
SGBM on a clip of just your bare table, you'd get a depth map full of
speckle and holes precisely on the table.

The marker solves this brutally well: the high-contrast black-and-white
pattern is uniquely identifiable, and the corner detector finds the same
four corners reliably in both views with sub-pixel precision.

### Reason 2 — A point isn't enough; you need a frame

Even if we DID triangulate the table successfully (let's say you put a
textured tablecloth on it and stereo SGBM works perfectly), we'd recover
the **table plane** — its height and orientation, but **not its in-plane
axes**.

A plane has 3 DOF: one for height, two for tilt. A coordinate frame has
6 DOF: 3 for translation, 3 for rotation. So the missing piece is the
**rotation about the table normal** — i.e., which direction along the
table is "X" and which is "Y"?

Without that, you'd have:
- table-Z (height) for any point. ✓
- table-X and table-Y. ✗

Robot retargeting needs all 6 DOF. "The mug is at table position (12 cm,
5 cm)" requires knowing what 12 cm in X means.

The ArUco marker is **chiral** — its pattern is asymmetric, so its X and
Y axes are well-defined. Detecting the marker gives you all 6 DOF of
the table frame in one shot.

### Alternatives if you ever want to drop the marker

You're not stuck with a marker. There are real alternatives that recover
the full 6-DOF frame:

1. **Texture the table.** A patterned tablecloth or a coffee table with
   strong wood grain gives stereo enough features to triangulate the
   surface. Fit a plane to the triangulated points → get the plane. Then
   orient it using one strong feature (a logo, a corner of an object,
   the edge of the table) → get X/Y. Sensitive to lighting and surface
   texture.

2. **Track the table edges.** If the camera can see the corners or edges
   of the table, those are strong geometric features. You can
   triangulate the corners, fit a rectangle, and use the rectangle's
   sides for X and Y. Practical only if your FOV reliably includes the
   edges.

3. **Multiple markers / objects.** Put two distinguishable objects on
   the table at known positions. Each gives a 3D point; the line between
   them gives you an X axis; the table normal completes the frame. Less
   robust than one well-detected ArUco.

4. **A larger fiducial like a ChArUco board** (which you already have
   for calibration). Same idea as our marker but with more redundancy.

5. **Detect a known object** (mug with a known shape, fixed known
   pattern). Conceptually fine but requires a prior 3D model and
   pose-estimation infrastructure.

The single ArUco we're using is essentially the *minimum-overhead*
version of these. It's small (8 cm), trivially detected, gives all 6
DOF, and only needs to be visible in one view to anchor that frame for
that frame.

### The deeper answer

**Stereo can recover the table's plane, but not its frame.** The
marker's job is to define the **frame**, not to provide depth. The
marker isn't a stereo input at all — it's a 6-DOF reference object.

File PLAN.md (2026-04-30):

# Plan: dexterous hand capture via WiLoR + stereo

> **Pick-up-where-we-left-off (read this first if starting a new session):**
>
> - Repo state: stages 1, 3, 4 of the main pipeline are committed (MediaPipe per-camera, stereo calibration, sparse 3D triangulation). See `README.md` for the full picture.
> - Stage 8 status: **Phases 0, 1, 2, minimal Phase 3, full Phase 3, and Phase 3 (anchored) all done.**
> - **Phase 3 (anchored) is the canonical pipeline.** Per view: PnP fits a 6-DOF pose to WiLoR's 2D keypoints; stereo wrist depth supplies a 1-DOF metric scale anchor `k = Z_stereo / t_pnp[2]`. Uniform 3D scaling preserves 2D projection, so the rendered overlay matches `scripts/viz/wilor_ar_monocular.py` (median PnP residual ~2 px) while the underlying mesh is metric.
> - **Phase 3 (full Umeyama)** is kept as a reference experiment. It re-fit the mesh as a global 7-DOF rigid transform — gave one mesh in one frame, but median 2D reprojection error blew up to 10 px (with a 27 px tail), worse than monocular WiLoR. The negative result is committed for posterity.
> - Verify the env still works at any time (run from repo root):
>     ```bash
>     .venv-hamer/bin/python scripts/experiments/wilor_sanity.py             # single image, fast
>     .venv-hamer/bin/python scripts/experiments/wilor_wrist_stereo.py       # 15-s clip, ~7 min on MPS
>     .venv-hamer/bin/python scripts/viz/wilor_ar_monocular.py               # per-view monocular AR (10-s wide clip)
>     .venv-hamer/bin/python scripts/experiments/wilor_phase3_umeyama.py     # full Umeyama fusion (reference experiment)
>     .venv-hamer/bin/python scripts/pipeline/08_wilor_canonical.py          # canonical: monocular pose + stereo depth
>     .venv-hamer/bin/python scripts/pipeline/08_wilor_canonical.py --bench  # adds per-stage perf trace
>     ```
>   `wilor_sanity.py` should print `device: mps  yolo: cpu`, detect 1 hand, pop open the overlay.
>   `08_wilor_canonical.py` runs through 300 frames at ~1 fps on warm MPS and pops open the SBS annotated video at the end.
> - **Device portability**: all wilor scripts use `_lib/device.py` (`pick_device()` / `configure_perf()`). Same script behaves correctly on macOS+MPS, Linux+CUDA (with fp16 ViT, TF32, multi-worker DataLoader), and CPU-only. On a fresh CUDA box, expect ~3–5× lower per-frame inference time vs MPS.
> - The WiLoR repo lives at `wilor/` (gitignored — large weights, separate license). If you re-clone it, follow the Phase 0 commands further down. The MANO models live at `wilor/models/MANO_{RIGHT,LEFT}.pkl` (you uploaded them) and are symlinked from `wilor/mano_data/` where the WiLoR config expects them. **Note:** WiLoR only ever loads `MANO_RIGHT.pkl` and uses the standard mirror trick for left hands — `MANO_LEFT.pkl` is symlinked but unused.
> - Tracked entry points: `pipeline/08_wilor_canonical.py` (canonical), `viz/wilor_ar_monocular.py` (visual baseline), `experiments/wilor_sanity.py`, `experiments/wilor_wrist_stereo.py`, `experiments/wilor_phase3_umeyama.py` (reference experiments).
> - Last run results live at `outputs/<date> - wilor sanity *`, `outputs/<date> - wilor stereo demo *`, `outputs/<date> - wilor ar overlay *`, `outputs/<date> - phase3 fused *`, `outputs/<date> - phase3 anchored *`.

---

Status as of `27 April 2026`: stages 1, 3, 4 of the README ladder are done
(MediaPipe per-camera, stereo calibration, sparse 3D triangulation). This
plan covers the next push — replacing MediaPipe with a MANO-producing model
(WiLoR primary, HaMeR fallback) so the captured dataset is rich enough to
retarget to *any* gripper.

## Why

The captured dataset is for **robot-manipulation imitation learning**. The
robot may eventually use a parallel-jaw gripper, a 3-finger gripper, or an
anthropomorphic hand — the dataset must be **richer than any specific
gripper** so retargeting code can project it onto whatever robot is being
trained.

Concretely that means we need, per-frame, per-hand:

- **MANO joint angles** — `(16, 3)` axis-angle, the canonical retargeting target
- **MANO mesh vertices** — `(778, 3)` metric, needed for hand-object contact
- **Wrist 6DoF** — translation + rotation in the world frame, from stereo
- **Hand-presence flag** — per slot, whether the estimate is trustworthy

MediaPipe gives 21 sparse keypoints per hand; downstream code would have to
fit MANO to those points anyway, with extra error. So we go directly to a
MANO-producing model.

## Model choice: WiLoR primary, HaMeR fallback

| | WiLoR | HaMeR |
|---|---|---|
| Source | https://github.com/rolpotamias/WiLoR (CVPR 2025) | https://github.com/geopavlakos/hamer (CVPR 2024) |
| Detector | Built-in fully-convolutional, no external dep | detectron2-based |
| MPS-compatibility on M2 | Likely fine (no detectron2) | detectron2 has no MPS support — would force CPU detection |
| Reported speed | Detection >130 fps (M / S variants); reconstruction is ViT-based | ~6 fps total on consumer GPU |
| Output | MANO params + mesh | MANO params + mesh |
| Robotics-literature usage | Newer, less | More established (DexCap, Bunny-VisionPro reference HaMeR) |

WiLoR wins on **ease of setup on this Mac** and on **inference speed**. Both
produce the same MANO output, so swap-cost is low if WiLoR has issues on our
egocentric-top-down distribution.

## Why our stereo gives us an unusual advantage

Both WiLoR and HaMeR are **monocular** by default — they predict pose +
shape but **absolute scale is ambiguous** (a small hand close vs a big hand
far look identical to a single camera). With our calibrated stereo we can
fix scale: triangulate stable landmarks (wrist, palm-base, middle-finger
MCP) from the two views, then rescale the monocular MANO output to match.
This is a stronger setup than the default literature pipeline gets.

## Phased plan (each phase independently testable)

### Phase 0 — environment & weights
- New venv: `.venv-hamer/` (separate from `.venv` to avoid PyTorch ↔ MediaPipe
  dep conflicts). Name kept generic so it's reusable if we swap WiLoR for
  HaMeR later.
- Clone repo: `git clone https://github.com/rolpotamias/WiLoR wilor/` into
  the project root (subdir, gitignored).
- Install: torch (with MPS), the wilor package, smplx, and whatever the
  upstream `setup.py` / `pyproject.toml` lists.
- Download WiLoR checkpoints via the upstream script.
- **User-required step**: register at `mano.is.tue.mpg.de`, download
  `MANO_RIGHT.pkl`, place at `wilor/mano_data/MANO_RIGHT.pkl` (path per
  upstream README).
- Validate: WiLoR demo runs on a stock sample image, produces a mesh.

### Phase 1 — single-frame, single-view sanity *(done)*
- Entry point: `scripts/experiments/wilor_sanity.py`.
- Runs YOLO (CPU — known MPS bug for Pose models) + WiLoR (MPS) on
  `inputs/24th April 2026 - photo cam0.jpg`. Outputs an OpenCV overlay
  (`outputs/<date> - wilor sanity overlay.jpg`) and the MANO mesh as a
  plain `.obj` (`outputs/<date> - wilor sanity hand0.obj`).
- **Result on the test capture (4608×2592):**
  - YOLO detected 1 hand correctly, labelled "right" (correct vs. MediaPipe
    which couldn't reliably get handedness on egocentric data — promising
    sign for our use case).
  - WiLoR mesh extent ~16.3 cm in MANO local frame — anatomically plausible.
  - 21 reprojected 2D keypoints land on the actual hand in the overlay.
  - Inference: YOLO 0.4 s on CPU; WiLoR 6.3 s on MPS for the *first* call
    (kernel compilation overhead). Sustained per-frame cost in Phase 2 will
    be much lower — we'll measure properly there.
- Pyrender doesn't load on macOS without OSMesa, so the sanity script stubs
  the three renderer-using submodules of `wilor.utils`. Inference works;
  visualisation will need a separate path in Phase 4 (probably trimesh or
  matplotlib).

### Phase 2 + minimal Phase 3 — per-view WiLoR with stereo wrist triangulation *(done as one combined demo)*
- Entry point: `scripts/experiments/wilor_wrist_stereo.py`. Default clip is the 15-s grease
  clip with the wide-FOV calibration; `--long` switches to the 60-s narrow
  clip preset. CLI args `--clip-left/--clip-right/--calib/--tag/--max-frames`
  override paths and limits — relative paths resolve against the repo root.
- Per frame pair:
  1. YOLO detect on the raw left + right frame (CPU; ultralytics MPS bug).
  2. WiLoR forward pass per detected hand per view (MPS, ~0.9 s warm).
  3. Project each hand's wrist 2D into rectified space via
     `cv2.undistortPoints(..., R=R1|R2, P=P1|P2)`.
  4. Match left/right hand detections by rectified wrist-row proximity
     (`ROW_TOL_PX = 30`).
  5. Triangulate matched wrists with `cv2.triangulatePoints(P1, P2, ...)` →
     metric wrist 3D in the left rectified camera frame.
  6. Sanity-filter wrist Z to `[5 cm, 200 cm]`. (5 cm not 10 — on a head-mount
     hands genuinely get this close when manipulating something near the face.)
  7. Annotate the SBS frame with the WiLoR skeleton, bbox, handedness label,
     and the metric `z=XX.X cm` if pairing succeeded.
- Output:
  - `outputs/<date> - wilor stereo demo {tag}.mp4` — SBS annotated video.
  - `outputs/<date> - wilor stereo demo {tag}.npz` — per-frame
    `wrist_3d_metric[N, 2, 3]`, `keypoints_2d_left/right[N, 2, 21, 2]`,
    `handedness[N, 2]`.

**Result on the 15-s grease clip (451 frames, 7.5 min wall time):**
- Inference 0.98 s/frame on warm MPS.
- Wrist depth (cm): median 34.1, 5–95 [6.5, 40.1], min 5.1, max 69.7.
- Median lines up well with what MediaPipe-stereo reported on similar
  footage (~33 cm), giving us a regression baseline.

**Why this is "minimal" Phase 3 and what's still ahead:**
- Only the wrist landmark is triangulated. The full Phase 3 (next section)
  triangulates all 21 landmarks and fits the entire MANO mesh into the
  shared world frame.

### Phase 3 (full Umeyama) — reference experiment *(done, kept for comparison)*

**Status.** Built and run on the wide 10-s clip; 596/600 pairs fused (99.3%);
median 2D reprojection error 10/11 px (left/right) with a 27 px tail.
**Worse than monocular WiLoR by every visual metric.** Replaced as the
canonical pipeline by Phase 3 (anchored) below — the negative result is
kept here so future-you (and future-readers) understands why the simpler
1-DOF anchor is preferred over the 7-DOF Umeyama refit.

**Why it was worse.** The 7-DOF (s, R, t) re-fit gave us cross-view 3D
consistency (one mesh, not two) at the cost of breaking WiLoR's per-view
2D accuracy. Triangulation noise on fingertips at the 41 mm baseline
propagates into the global rigid transform; weighted Umeyama mitigates
but doesn't eliminate it. The lesson: don't fight the model. WiLoR was
trained for monocular 2D + relative 3D and is excellent at that — only
add what stereo can give that monocular cannot, which is absolute scale.

**Goal (as designed).** For each frame and each detected hand, produce
*one* MANO mesh in the rectified-left camera frame at metric scale,
consistent with both views' WiLoR predictions.

**The core unknowns per matched hand per frame: a similarity transform
(s, R, t) — 7 DOF.** That places WiLoR's MANO output (in its own root-
centered local frame) into the rectified-left camera frame. WiLoR's pose θ
and shape β stay as predicted for the first iteration; β refinement is
Phase 3.5.

**Algorithm — two steps, the second is optional:**

1. **Umeyama (closed-form)** — triangulate all 21 keypoints to get 21 metric
   3D points; solve `Σᵢ wᵢ ‖triangulated_3d[i] − (s·R·pred_kp3d_local[i] + t)‖²`
   via SVD (Umeyama 1991, weighted variant). Closed form, no iteration.
2. **Levenberg–Marquardt (refinement, Phase 3.4)** — minimize 2D reprojection
   error across both views over `(s, axis_angle_R, t)` with a robust loss.
   Initialize from step 1.

**Phased implementation. Each substep is independently testable.**

| Substep | What | Status |
|---|---|---|
| 3.1 | Triangulate all 21 keypoints per matched hand. Per-keypoint validity = (rectified-row agreement < 8 px) & (Z plausible). | in progress |
| 3.2 | Weighted Umeyama. Down-weight fingertips (1 px disparity → big depth error at 41 mm baseline). Apply `(s, R, t)` to all 778 vertices. | in progress |
| 3.3 | Project the world-frame mesh into both unrectified views via `R1.T` (undo rectification) + `cv2.projectPoints` with `K_l/K_r, dist_l/dist_r`. Render with the same painter's-algorithm code as `scripts/viz/wilor_ar_monocular.py`. | in progress |
| 3.4 | LM refinement of `(s, R, t)` against 2D reprojection error in both views. `scipy.optimize.least_squares` with `loss="soft_l1"`. | deferred |
| 3.5 | Joint solve over `(s, β, R, t)` — adds shape refinement. Stereo identifies β; monocular β is ill-posed. | deferred |
| 3.6 | Sequence smoothing. Belongs in Phase 4 if jitter is bothersome. | deferred |

**File plan.** Single entry point: `scripts/experiments/wilor_phase3_umeyama.py` (was `wilor_phase3.py` before the reorg). Outputs:

- `outputs/<date> - phase3 fused [<tag>].npz` — schema below.
- `outputs/<date> - phase3 ar overlay [<tag>].mp4` — SBS, fused mesh
  rendered into both **unrectified** frames so it's directly comparable to
  the per-view monocular `scripts/viz/wilor_ar_monocular.py` output.

**Output schema (`.npz`):**

```
verts_3d_world      (N, 2, 778, 3)  float32 — world (= rectified-left) frame, NaN where missing
kp_3d_world         (N, 2,  21, 3)  float32 — triangulated, per-keypoint NaN where invalid
kp_valid            (N, 2,  21)     bool    — row-tolerance + Z-bound mask
placement_s         (N, 2)          float32 — Umeyama scale
placement_R         (N, 2,  3, 3)   float32 — Umeyama rotation
placement_t         (N, 2,  3)      float32 — Umeyama translation
umeyama_residual_m  (N, 2)          float32 — mean residual after fit, metres
reproj_err_left_px  (N, 2)          float32 — median 2D error of fused mesh keypoints in left
reproj_err_right_px (N, 2)          float32 — same for right
handedness          (N, 2)                  — strings
fps, image_size, calib_path                   self-contained for downstream code
```

**Validation (what makes 3.1–3.3 a "success"):**

1. **Reprojection error.** Median < 5 px after Umeyama in both views; > 10 px
   means coordinate-frame mismatch or wrong-hand pairing.
2. **Wrist agreement.** Fused mesh's wrist position matches the directly-
   triangulated wrist (minimal Phase 3) to within 1 mm — same point, two
   ways.
3. **Visual.** Fused-mesh AR overlay video shows fingertips landing on the
   same physical fingertip in both views (which is *not* reliable in
   `scripts/viz/wilor_ar_monocular.py`'s independent per-view meshes).

**Risks and mitigations:**

- *Fingertip triangulation noise* — weighted Umeyama (palm joints heavier).
- *Cross-view chirality flip* (left view sees "right hand", right view sees
  "left hand" for the same physical hand) — known issue, document for now,
  fix by relabeling chirality based on rectified wrist X position.
- *Outlier hand pairings* — if Umeyama residual > 2 cm, fall back to wrist-
  only fusion (the minimal Phase 3 result) and flag the frame.
- *WiLoR's `pred_keypoints_3d` frame convention* — assumed root-centered
  MANO local. Will verify at runtime by checking `kp3d[0] ≈ 0`.

### Phase 3 (anchored) — monocular pose + stereo metric depth *(canonical)*

**Goal.** Same as Phase 3 (full): produce a metric MANO mesh per matched-hand
pair. **But solve only what stereo can uniquely give: absolute scale.**
Trust WiLoR's monocular fit for everything else.

**Algorithm.** Per matched-hand pair, per view:

1. WiLoR forward pass — `pred_vertices` (778, 3 in MANO local frame),
   `pred_keypoints_3d` (21, 3 same frame, root-centered),
   `pred_keypoints_2d_full` (21, 2 in real-image pixels).
2. **`cv2.solvePnP(SQPNP)`** — fit (R_view, t_view) such that
   `K · (R_view·X_local + t_view)` projects to WiLoR's 2D keypoints.
   t_view[2] is WiLoR's monocular wrist depth estimate in the real
   camera frame.
3. **Stereo triangulate the wrist** in rectified-left frame, then transform
   into each real camera frame to get `Z_stereo_view`.
4. **Scalar scale anchor**: `k_view = Z_stereo_view / t_view[2]`. (1 DOF.)
5. **Metric mesh**: `mesh_metric_view = k_view · (R_view · verts_local + t_view)`,
   in each real camera frame. Render via `cv2.projectPoints` through
   (K_view, dist_view).

**Why this works (math).** *Uniform 3D scaling preserves perspective 2D
projection.* `(X, Y, Z) → (fX/Z, fY/Z)`; scale to `(kX, kY, kZ)` →
`(fkX/kZ, fkY/kZ)` = same 2D. So we can change the metric size of the
mesh without breaking WiLoR's pixel-perfect 2D fit. Stereo gives us
exactly one piece of information that monocular cannot: absolute scale.
We use it for that, and only that.

**Result on the wide 10-s clip:**
- 596/600 pairs anchored (99.3%, same as Phase 3 full).
- **Median 2D reprojection ~2 px** (5–95 [0.9, 6 px]) — visually
  indistinguishable from `scripts/viz/wilor_ar_monocular.py`.
- Wrist depth median 45.9 cm — agrees with Phase 3 (full) exactly
  (both pipelines triangulate the same wrist).
- Per-view scale `k` typically agrees within ~3% (k_L ≈ k_R per frame),
  which is the genuine cross-view sanity check: stereo is giving us a
  consistent metric size, not just a depth.

**Output schema (`.npz`):**

```
verts_3d_world           (N, 2, 778, 3)  metric MANO mesh in rectified-left frame,
                                          derived from LEFT view (canonical), NaN where missing
wrist_3d_world           (N, 2, 3)       stereo-triangulated wrist
pose_R_left              (N, 2, 3, 3)    PnP rotation in original-left cam frame
pose_t_left              (N, 2, 3)       PnP translation in original-left cam frame
pose_R_right             (N, 2, 3, 3)    PnP rotation in original-right cam frame
pose_t_right             (N, 2, 3)       PnP translation in original-right cam frame
scale_k_left             (N, 2)          1-DOF anchor for left view
scale_k_right            (N, 2)          1-DOF anchor for right view
pnp_residual_left_px     (N, 2)          PnP fit quality
pnp_residual_right_px    (N, 2)          PnP fit quality
handedness               (N, 2)          strings
fps, image_size, calib_path                self-contained
```

**Trade-offs vs Phase 3 (full):**

| | Phase 3 (full Umeyama) | Phase 3 (anchored) |
|---|---|---|
| 2D pixel accuracy | poor (10–27 px) | excellent (1–2 px) |
| Metric depth | yes | yes |
| Cross-view 3D agreement | yes by construction (one mesh) | partial — wrists agree, rest may drift slightly |
| DOF solved with stereo | 7 (s, R, t) | **1 (s only)** |
| Sensitivity to fingertip triangulation | high | very low (only wrist matters) |

For the dataset we're producing (Phase 5 — robot-training export), the
canonical 3D representation is `verts_3d_world` from the anchored
output. The anchored mesh in left-cam frame transformed to world
(rectified-left) frame is what downstream retargeting code consumes.

### Phase 4 — visualization & validation
- Side-by-side rectified video with mesh overlay (extends `triangulate.py`'s
  output style).
- Trajectory plots: wrist 6DoF over time, per-finger flexion over time
  (extends `scripts/viz/inspect_3d_mp.py`).
- Sanity bounds: mesh volume in physically plausible range; joint angles
  inside MANO's training distribution.
- Cross-check: wrist trajectory should agree with the existing
  MediaPipe-stereo `.npz` from stage 4 to within a few mm. Disagreement is a
  flag.

### Phase 5 — robot-training export
- Final dataset format (`outputs/<date> - manipulation dataset.npz` or `.h5`):
  - `mano_pose[N, 2, 16, 3]`
  - `mano_betas[N, 2, 10]`
  - `vertices[N, 2, 778, 3]` metric, world frame
  - `wrist_6dof[N, 2, 6]` translation + axis-angle rotation
  - `hand_present[N, 2]` boolean
  - `timestamps[N]`
  - `intrinsics`, `extrinsics` (copied from calibration `.npz` for self-containment)
- Schema documented inline so retargeting code can consume without
  reverse-engineering.

## Where existing code fits

| Existing | Role going forward |
|---|---|
| `scripts/pi/dualstream.py` | Pi-side capture, unchanged |
| `scripts/calibration/make_charuco_board.py`, `scripts/calibration/calibrate_stereo.py` | Provide the calibration `.npz` that fixes stereo scale — unchanged |
| `scripts/calibration/make_aruco_marker.py` | Generates the table-anchor fiducial PDF (Phase 4–5 prep) |
| `scripts/pipeline/04_triangulate_mp.py` (MediaPipe stereo) | Kept as **fast preview path** (~37 fps) and as a **regression baseline** — wrist trajectories should agree with WiLoR-stereo |
| `scripts/experiments/wilor_wrist_stereo.py` | The **Phase 2** reference (wrist-only stereo). Kept as the regression baseline for the canonical pipeline |
| `scripts/viz/wilor_ar_monocular.py` | The **per-view monocular** AR overlay. Stays as the regression baseline for visual mesh consistency. Has full CUDA/MPS portability via `_lib/device.py`. |
| `scripts/experiments/wilor_phase3_umeyama.py` | The **Phase 3 (full Umeyama)** reference experiment. Stays in the tree as the "we tried 7-DOF refit and it was worse" record |
| `scripts/pipeline/08_wilor_canonical.py` | The **canonical Phase 3**: PnP per view + stereo wrist depth → 1-DOF scale anchor. Renders match `viz/wilor_ar_monocular.py` (uniform scaling preserves 2D); meshes are metric. Phase 5 dataset export consumes this. Has full CUDA/MPS portability + `--bench` perf trace mode. |
| `scripts/viz/inspect_3d_mp.py` | Extended in phase 4 for MANO trajectory plots |
| `scripts/viz/stitch_panorama.py`, `scripts/viz/play_stereo.py`, `scripts/viz/depth_dense.py` | Debug viewers — not on the canonical pipeline, but useful for visual sanity checks |

## Risks & open questions

- **MPS coverage**: PyTorch MPS supports most ops needed for transformer
  inference, but WiLoR may use ops that fall back to CPU. Plan: try, accept
  warnings, only act if inference is unusably slow.
- **Egocentric extreme angles**: top-down hand poses on a head-mount may sit
  at the edge of WiLoR's training distribution. Phase 1 will tell us.
- **Detection misses**: even single-stage, WiLoR has a confidence floor. We
  compare detection rates against MediaPipe's 99% / 93% as the regression
  baseline.
- **Scale fusion correctness**: assumes monocular shape is right *up to
  scale*. If WiLoR's shape predictions are noisy frame-to-frame the scale
  factor will jitter. Mitigation: low-pass-filter the scale over short
  windows, or fit a single shape per identity offline.

## Decisions to make as we go

- WiLoR repo location: `wilor/` subdir (gitignored) vs sibling dir.
  **Default: subdir.** *(decided)*
- Data format: `.npz` (simple) vs `.h5` (better for big datasets).
  **Default: `.npz` until total dataset > ~1 GB.**
- Whether to keep MediaPipe pipeline running alongside WiLoR for every clip,
  or only as needed. **Default: alongside, since it's cheap and useful as
  regression check.**

### Open after Phase 2 + minimal Phase 3

- (a) **Proper Phase 3 — full mesh scale fusion.** *Done both ways.* The
  Umeyama 7-DOF refit (`scripts/experiments/wilor_phase3_umeyama.py`) was tried first and produced
  worse 2D accuracy than monocular WiLoR. The anchored 1-DOF approach
  (`scripts/pipeline/08_wilor_canonical.py`) preserves WiLoR's 2D and uses stereo only
  for absolute scale — that's now the canonical pipeline. Both kept in
  the tree.
- (b) **Better hand-to-hand matching.** Replace the greedy single-landmark
  match with a multi-landmark Hungarian assignment (use 3–4 stable
  landmarks per hand, not just the wrist). Specifically helps the
  "stereo paired but rejected" cases where two hands are gripping the
  same object and their wrists are at near-identical Y in rectified space.
  Becomes more relevant once Phase 3 is producing reliable per-frame meshes.
- (c) **Run on the 60-s "first minute" clip.** Same pipeline, just longer
  footage with much more varied interactions. ~30 min wall time. Good
  for evaluating the demo; doesn't change quality.

## Quick-reference setup commands (Phase 0)

```bash
# from /Users/kanavgupta/Desktop/cameramount
brew install python@3.10                # macOS only had 3.9.6; WiLoR wants 3.10
python3.10 -m venv .venv-hamer
.venv-hamer/bin/pip install --upgrade pip wheel

# --recursive picks up upstream submodules
git clone --recursive https://github.com/rolpotamias/WiLoR wilor

# WiLoR's requirements.txt pins torch+cu117. We use the default PyTorch index
# instead, which gives a build with MPS (Apple Metal) support on macOS.
.venv-hamer/bin/pip install torch torchvision

# Cython is needed at build time for xtcocotools' C extension.
.venv-hamer/bin/pip install Cython

# chumpy's setup.py imports `pip` directly, which fails inside pip's isolated
# build env. Install it separately with --no-build-isolation so it can see the
# venv's pip. Then install the rest of the requirements (also with
# --no-build-isolation so subsequent C-extension builds see numpy).
.venv-hamer/bin/pip install --no-build-isolation \
  "chumpy @ git+https://github.com/mattloper/chumpy"
grep -v "^chumpy" wilor/requirements.txt > /tmp/wilor_reqs.txt
.venv-hamer/bin/pip install --no-build-isolation -r /tmp/wilor_reqs.txt

# Pretrained checkpoints (51 MB detector + 2.4 GB MANO regressor)
curl -L -o wilor/pretrained_models/detector.pt \
  https://huggingface.co/spaces/rolpotamias/WiLoR/resolve/main/pretrained_models/detector.pt
curl -L -o wilor/pretrained_models/wilor_final.ckpt \
  https://huggingface.co/spaces/rolpotamias/WiLoR/resolve/main/pretrained_models/wilor_final.ckpt

# MANO model (academic license — must be done by user):
#   1. Register at https://mano.is.tue.mpg.de/
#   2. Download MANO_RIGHT.pkl (the right-hand model file)
#   3. Place at wilor/mano_data/MANO_RIGHT.pkl
#      (smplx looks for "MANO_{RIGHT,LEFT}.pkl" inside the configured dir;
#       WiLoR config sets MANO.MODEL_PATH = './mano_data/'.)
```

### Install gotchas encountered (worth keeping a note of)

- **`chumpy` git install fails under build isolation** — its `setup.py` does
  `import pip`, which is not present in the isolated build env. Workaround:
  `pip install --no-build-isolation "chumpy @ git+..."`.
- **`xtcocotools` build needs Cython + numpy at build time** — install Cython
  first, then run the rest of the install with `--no-build-isolation` so the
  C extension build can see the venv's numpy.
- **PyTorch CUDA pin in `requirements.txt`** — the upstream pins `cu117`.
  On Apple Silicon you want the default-index torch (MPS-enabled). Install
  `torch torchvision` first from the default index, then install the rest
  of the requirements (which won't try to re-resolve torch).
- **`dill` not in requirements** — the YOLO `detector.pt` was pickled with
  `dill`, but WiLoR's `requirements.txt` doesn't list it. Install separately:
  `pip install dill`.
- **PyTorch 2.6 broke YOLO checkpoint loading** — `torch.load`'s default
  flipped to `weights_only=True`. The YOLO ckpt has pickled class refs and
  can't load under that default. The sanity script monkey-patches
  `torch.load` to `weights_only=False` (we trust both checkpoint sources from
  upstream HuggingFace). When ultralytics > 8.3 lands, this won't be needed.
- **Pyrender doesn't load on macOS** — needs EGL or OSMesa, neither of which
  is on macOS by default. The sanity script stubs the three renderer-using
  submodules of `wilor.utils` so inference works. Real 3D viz comes later.
- **YOLO MPS bug for Pose models** — ultralytics issue #4031 documents that
  Pose-task YOLO models on MPS are broken / extremely slow (NMS time-limit
  warnings, 11 s vs 0.4 s on CPU on this rig). Run the detector on CPU and
  WiLoR on MPS — the detector is fast on CPU anyway.
- **MPS doesn't support `float64`** — the WiLoR dataset emits some float64
  tensors (`box_size` etc.). The sanity script casts those to `float32`
  before the `.to(device)` call. If we keep MPS for Phase 2, that cast goes
  in the per-clip pipeline too.
- **WiLoR repo layout vs sys.path** — `cameramount/wilor/` and
  `cameramount/wilor/wilor/` both have no `__init__.py`. If the repo root
  (cameramount/) is on sys.path, Python merges them into a single namespace
  package and `wilor.models` resolves ambiguously (`cameramount/wilor/models/`
  is where the user uploaded MANO files, which isn't a Python package).
  After the `scripts/` move, the repo root is no longer on sys.path
  implicitly; the wilor scripts just insert WILOR_DIR.
- **Left-hand 2D keypoints come out in flipped-crop coords** —
  `wilor/wilor/datasets/vitdet_dataset.py:62` flips the input crop
  horizontally for left hands (`flip = right == 0`). The network's
  `pred_keypoints_2d` and `pred_vertices` therefore come out in flipped
  coords. To map back to the original image / left-hand anatomy, multiply
  the X coordinate by `-1` for left hands BEFORE applying
  `box_center + box_size`. Without this, the rendered skeleton sits at
  mirrored X positions inside the bbox — looks vaguely hand-shaped (because
  hands are roughly symmetric) but anatomically wrong (thumb and pinky
  swapped), and biases the triangulated wrist X toward the bbox center.
  Bug found and fixed during the stereo demo run; see all wilor entry points
  under `scripts/experiments/`, `scripts/viz/wilor_ar_monocular.py`, and
  `scripts/pipeline/08_wilor_canonical.py`.
- **YOLO/WiLoR handedness labels are unreliable on egocentric footage** —
  same finding as MediaPipe (documented in README's "Other known
  limitations"). The same physical hand can be labelled "right" in one view
  and "left" in the other. Doesn't affect 3D positions; only the labels.
  Cheap fix: relabel based on which side of the frame the wrist sits on.
  Not blocking for Phase 3.

## Glossary (so future-you doesn't have to look these up)

- **MANO** — Embodied Hands parametric model. 16 joints × 3 axis-angle
  rotations for pose, 10 betas for shape. Outputs a 778-vertex mesh.
- **Axis-angle** — 3-vector encoding rotation; direction is rotation axis,
  magnitude is angle. Compact alternative to rotation matrices.
- **Rectification** — virtual rotation of stereo views so corresponding
  points lie on the same image row. Computed once in `calibrate.py`,
  reused via `cv2.remap`.
- **Epipolar constraint** — for any 3D point seen by both cameras, its image
  in the right view lies on the *epipolar line* of the left view's point.
  After rectification, all epipolar lines are horizontal, so the constraint
  becomes "same row".
- **Triangulation** — given a point's pixel coordinates in two calibrated
  views, recover its 3D position. `cv2.triangulatePoints(P1, P2, ...)`.

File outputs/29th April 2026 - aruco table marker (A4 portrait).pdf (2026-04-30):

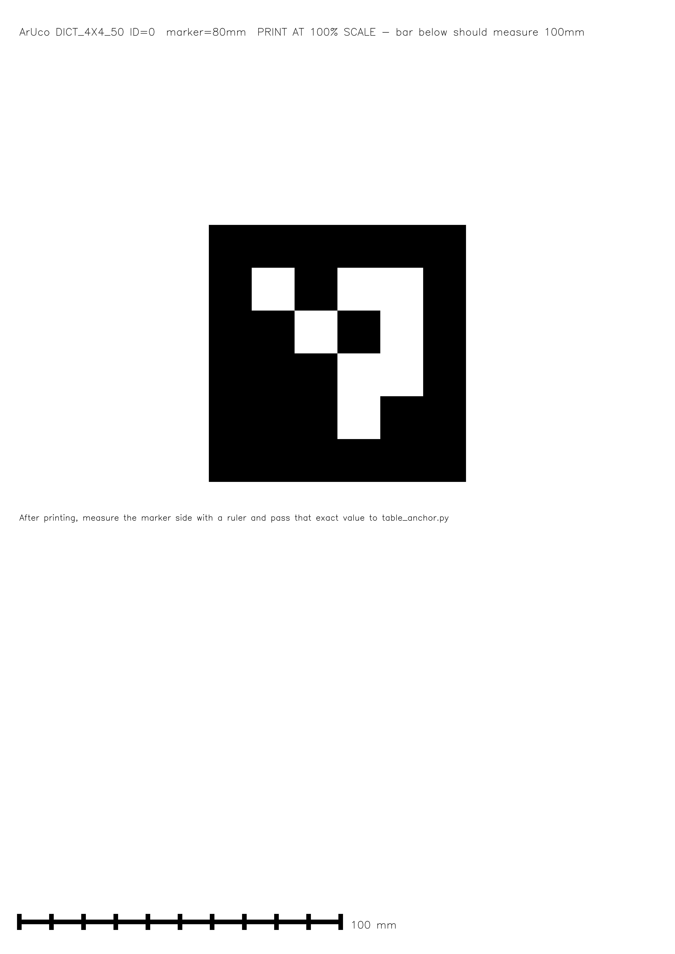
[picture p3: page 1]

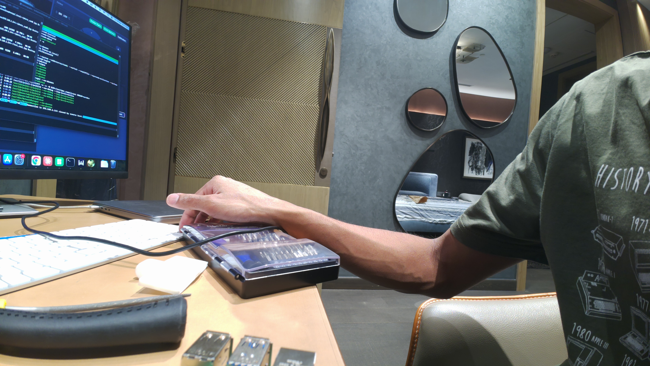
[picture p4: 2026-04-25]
inputs/24th April 2026 - photo cam0.jpg

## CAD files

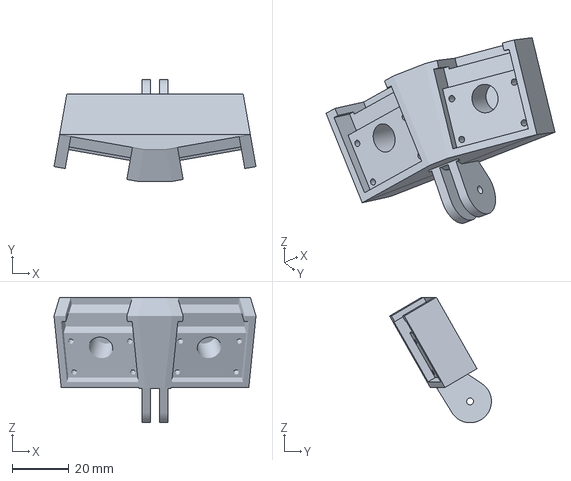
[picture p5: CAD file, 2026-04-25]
cad/dual_picam3_holder_v2.3mf
71.0 x 35.8 x 44.1 mm

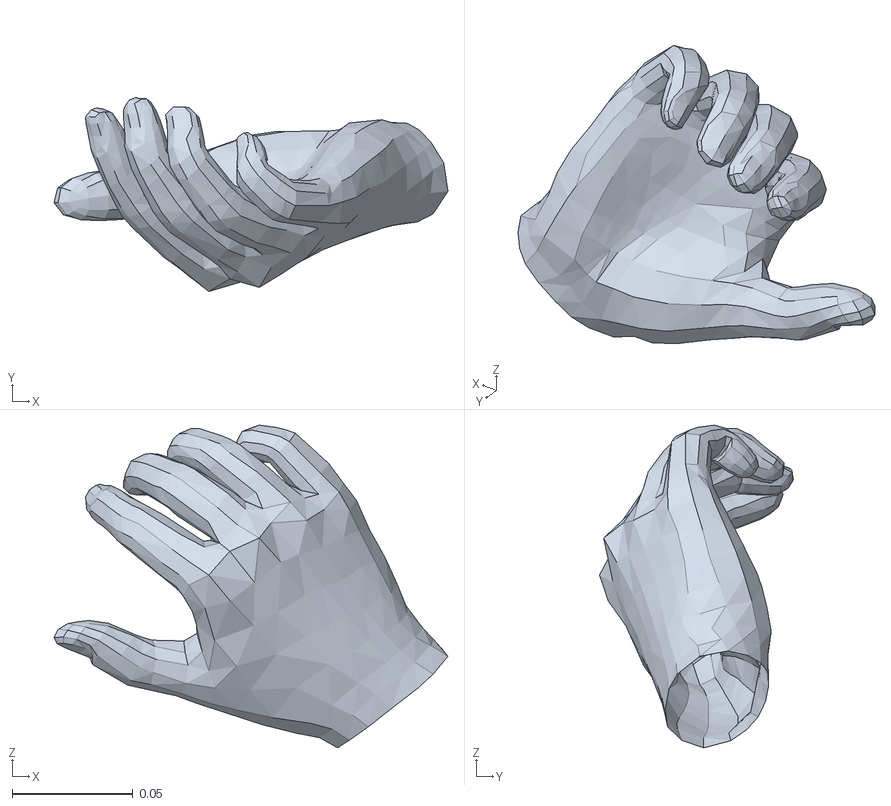
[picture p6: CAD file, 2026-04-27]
outputs/27th April 2026 - wilor sanity hand0.obj
0.163 x 0.0803 x 0.134

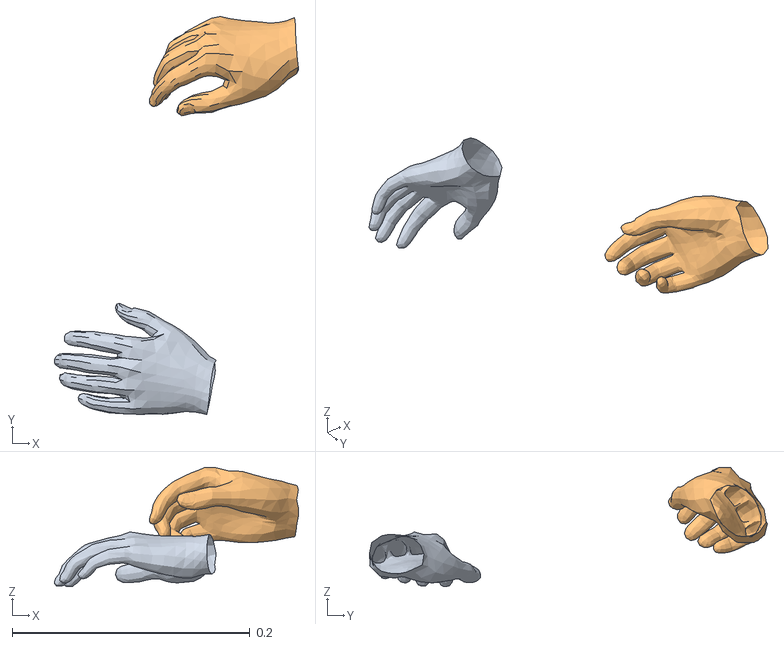
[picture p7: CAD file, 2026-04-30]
outputs/30th April 2026 - mesh sequence [20260430 manipulation]/mesh_0514.obj
0.206 x 0.335 x 0.1
hand_slot0
hand_slot1

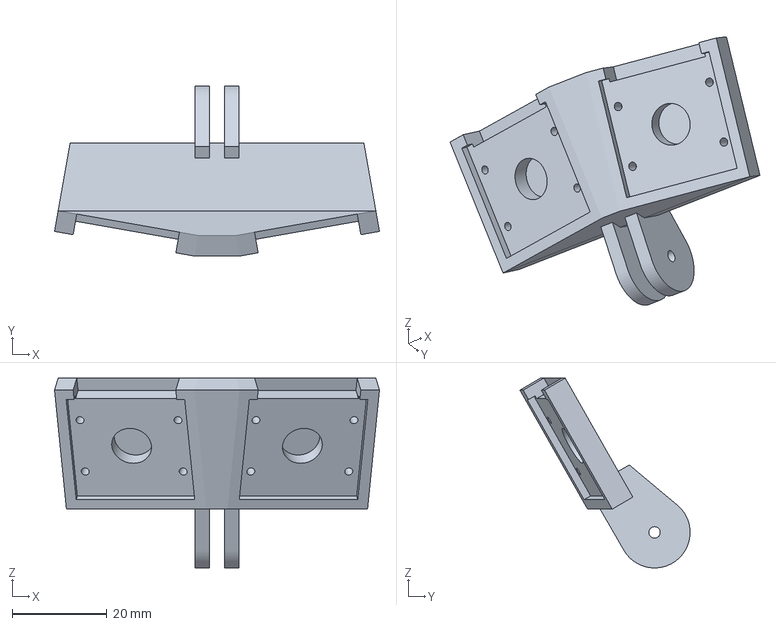
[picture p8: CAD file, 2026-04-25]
cad/dual_picam3_holder.3mf
68.6 x 35.9 x 40.1 mm

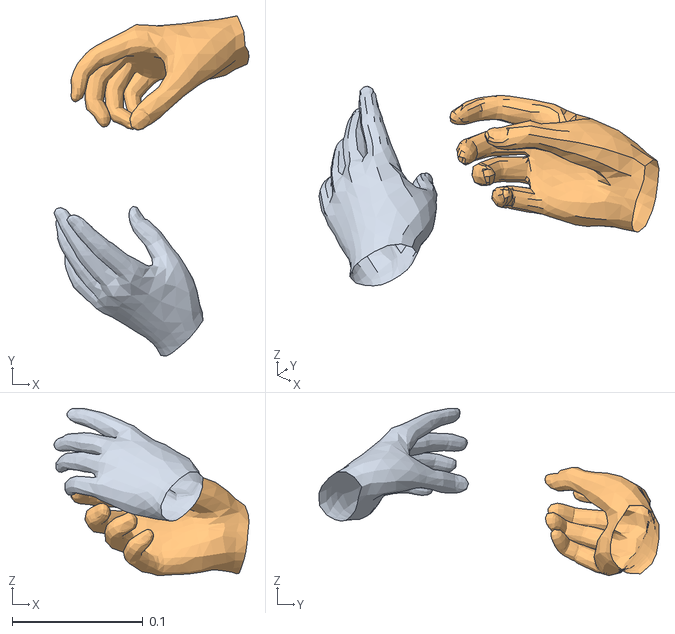
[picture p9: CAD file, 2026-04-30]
outputs/30th April 2026 - mesh sequence [20260430 manipulation]/mesh_0344.obj
0.149 x 0.26 x 0.128
hand_slot0
hand_slot1

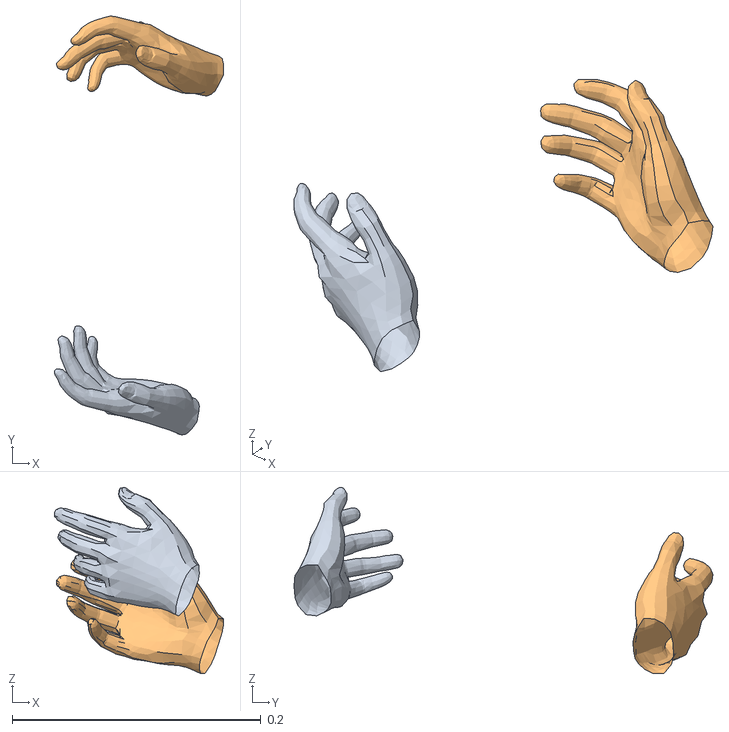
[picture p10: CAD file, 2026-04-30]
outputs/30th April 2026 - mesh sequence [20260430 manipulation]/mesh_0114.obj
0.136 x 0.337 x 0.15
hand_slot0
hand_slot1

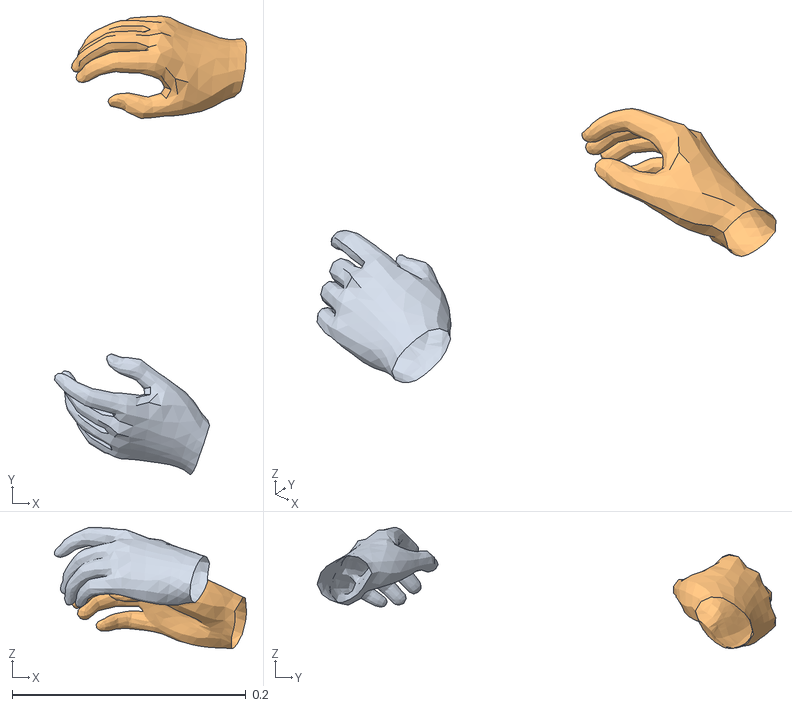
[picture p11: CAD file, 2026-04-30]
outputs/30th April 2026 - mesh sequence [20260430 manipulation]/mesh_0125.obj
0.164 x 0.393 x 0.104
hand_slot0
hand_slot1

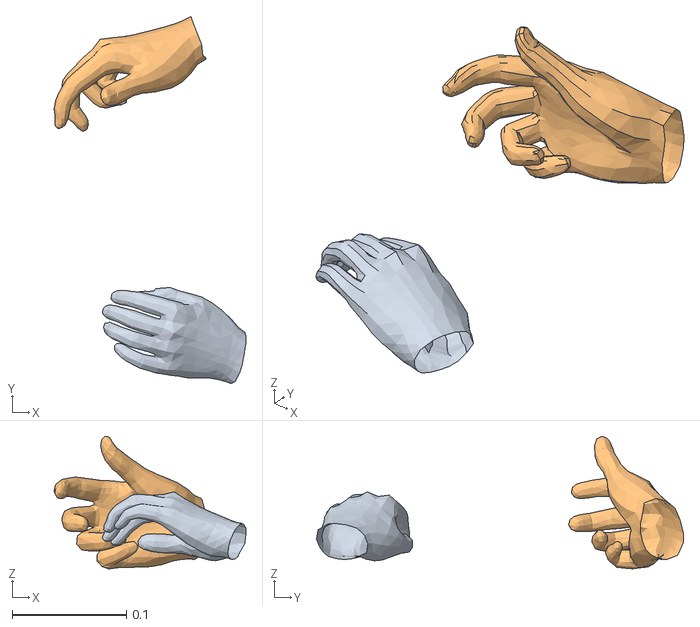
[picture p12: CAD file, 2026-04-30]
outputs/30th April 2026 - mesh sequence [20260430 manipulation]/mesh_0444.obj
0.168 x 0.321 x 0.116
hand_slot0
hand_slot1

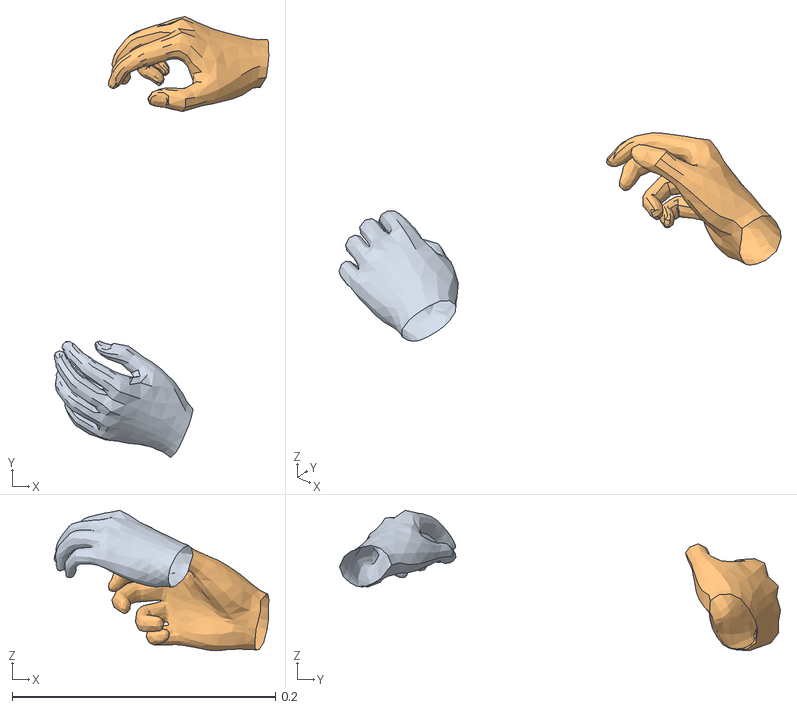
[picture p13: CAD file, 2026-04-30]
outputs/30th April 2026 - mesh sequence [20260430 manipulation]/mesh_0160.obj
0.163 x 0.335 x 0.107
hand_slot0
hand_slot1

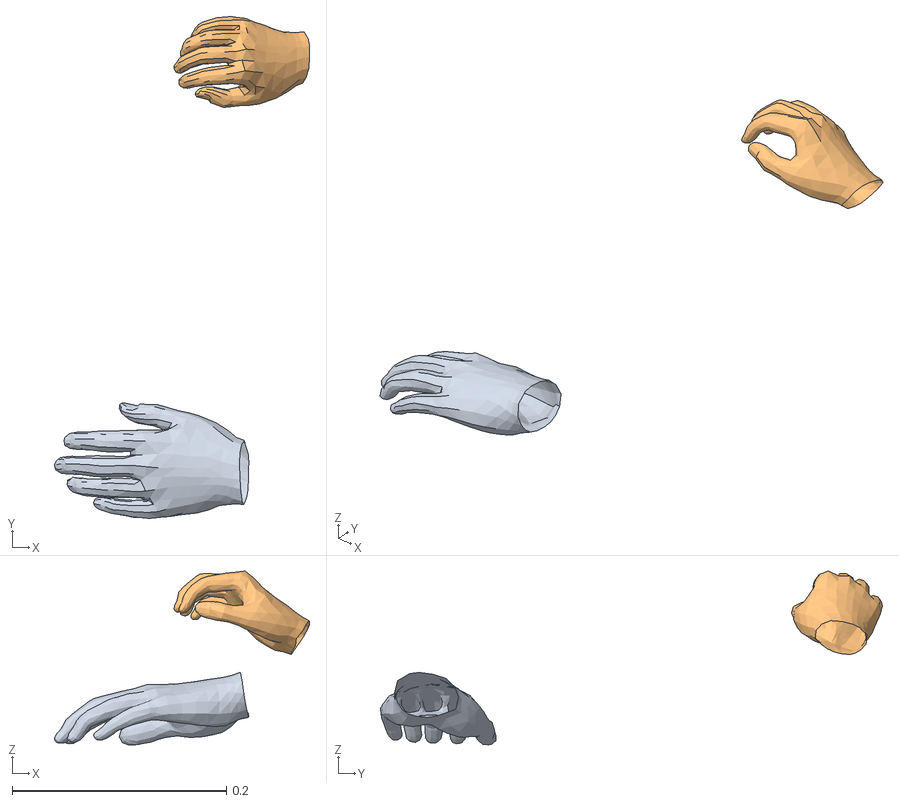
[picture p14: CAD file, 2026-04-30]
outputs/30th April 2026 - mesh sequence [20260430 manipulation]/mesh_0031.obj
0.238 x 0.468 x 0.162
hand_slot0
hand_slot1

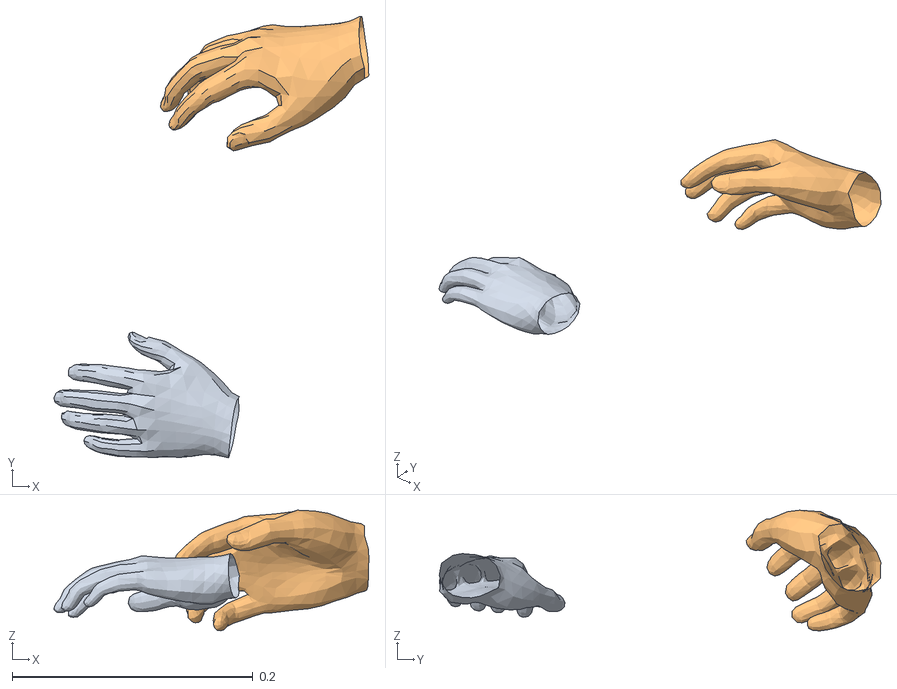
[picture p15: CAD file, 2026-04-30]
outputs/30th April 2026 - mesh sequence [20260430 manipulation]/mesh_0517.obj
0.262 x 0.367 x 0.1
hand_slot0
hand_slot1

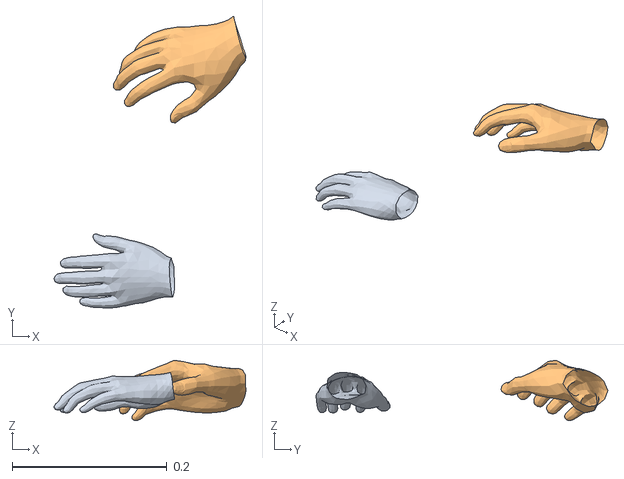
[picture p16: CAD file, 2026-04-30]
outputs/30th April 2026 - mesh sequence [20260430 manipulation]/mesh_0009.obj
0.248 x 0.378 x 0.0783
hand_slot0
hand_slot1

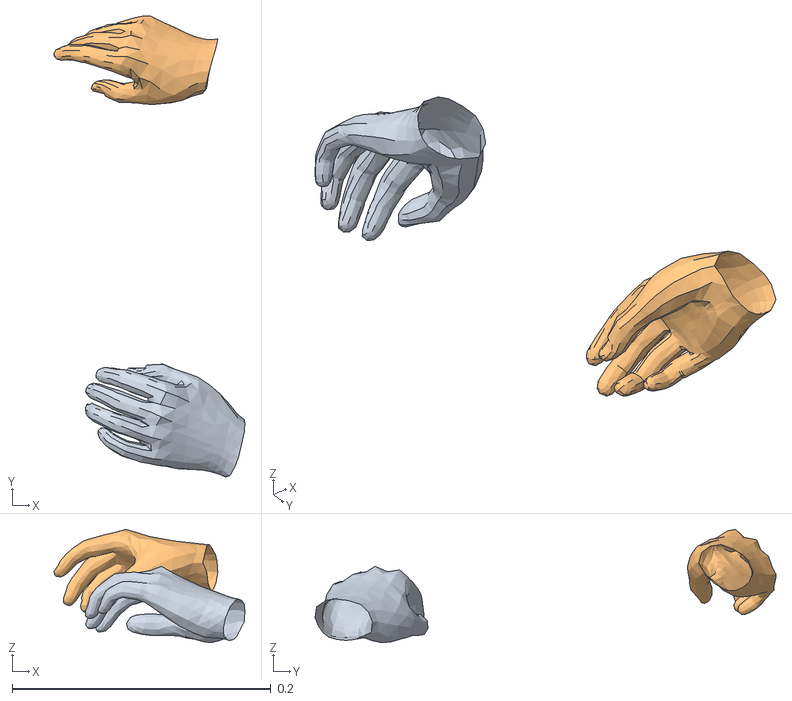
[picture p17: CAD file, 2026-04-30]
outputs/30th April 2026 - mesh sequence [20260430 manipulation]/mesh_0497.obj
0.148 x 0.357 x 0.0875
hand_slot0
hand_slot1

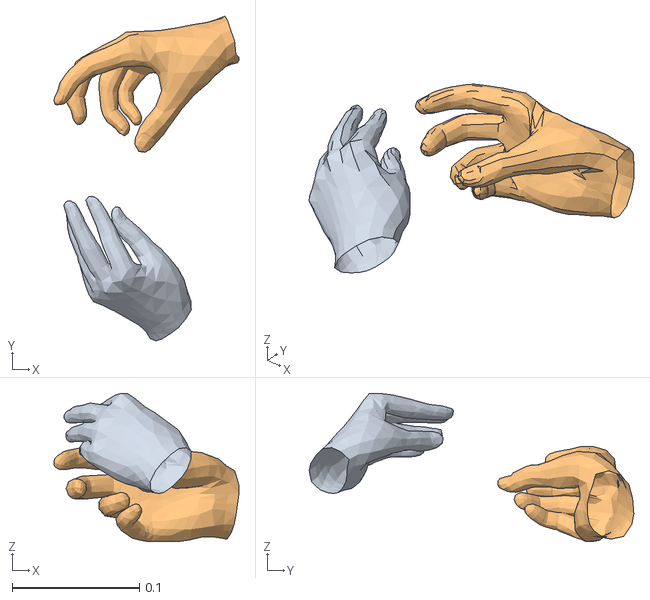
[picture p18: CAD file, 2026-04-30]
outputs/30th April 2026 - mesh sequence [20260430 manipulation]/mesh_0361.obj
0.146 x 0.256 x 0.117
hand_slot0
hand_slot1

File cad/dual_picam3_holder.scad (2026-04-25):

// ============================================================
//  Dual Raspberry Pi Camera Module 3 Holder
//  Head-mounted rig, optimized for hand-tracking + scene capture
//
//  Inspired by Printables #396799 (makerbymistake) but restructured:
//    • Both cameras pitched DOWN together (hands live in lower FOV)
//    • Toe angle parameter (+ toe-in, − toe-out)
//    • Adjustable baseline (lens-to-lens spacing)
//    • M2 screw retention for PCB (no friction-fit)
//    • Single M2 mount hole in the bottom tab
//
//  Coordinate convention (world frame):
//    +X = right, +Y = forward (user's gaze), +Z = up
//  Camera local frame (inside camera_plate):
//    +Y = lens-forward, PCB sits in the XZ plane at the back of the plate,
//    +Z = top of PCB (ribbon connector side)
// ============================================================

// ---------------- PRIMARY GEOMETRY (tune freely) ----------------
baseline        = 35;    // mm, lens-center to lens-center
pitch_angle     = -30;   // deg, both cameras pitch DOWN (+ = down, − = up)
toe_in_angle    = 10;    // deg per camera (+ toe-in, − toe-out)

// ---------------- CAMERA MODULE 3 SPEC ----------------
// (Leave alone unless targeting a different board)
pcb_w              = 25;    // PCB width
pcb_h              = 24;    // PCB height
pcb_t              = 4.2;   // PCB overall thickness (used for preview only)
lens_dia           = 8.5;   // lens-barrel clearance diameter
lens_offset_z      = 0;     // lens vertical offset from PCB center (0 = centered)
ribbon_w           = 22;    // ribbon cable exit slot width
ribbon_h           = 2.5;   // ribbon cable thickness clearance

// ---------------- PCB POCKET SHAPE (stepped) ----------------
// The Camera Module 3 is thicker at the ribbon-connector end (FPC
// connector sticks ~5 mm off the PCB back) and thinner everywhere else
// (just 3–3.5 mm of chip height).  We cut a STEPPED pocket so the
// plastic behind the chip zone is maximally thick (= strongest screw
// engagement) while the connector zone gets the extra clearance it
// needs.  The deeper region is anchored to the ribbon end (+Z side).
// Measured off the physical board:
//   • Chips on the back of the PCB stand ~2.5 mm off the PCB surface.
//   • The FPC connector stands ~4.3 mm ABOVE the chips, so total
//     clearance needed in the connector zone = 2.5 + 4.3 = 6.8 mm
//     (we reference every depth to the PCB surface, not to the chips).
//   • The FPC connector body is ~6 mm tall measured from the ribbon
//     edge inward → connector_zone_h = 6.
connector_pocket_d = 6.8;   // pocket depth under the ribbon connector
chip_pocket_d      = 2.5;   // pocket depth under the rest of the PCB
connector_zone_h   = 6.0;   // height of connector zone measured from
                            //   the ribbon edge of the PCB (+Z side)

// ---------------- M2 MOUNTING HOLES ----------------
// Four holes at the four corners of the PCB mounting pattern.
// Anchored at the PCB edge OPPOSITE the ribbon connector (call it
// the "top" edge — in this code's local frame, that's the −Z edge,
// because the ribbon exits at +Z).
//   - "Top" row: two holes hole_top_inset mm in from the far-from-
//     ribbon edge (top-left and top-right corners of the PCB).
//   - "Bottom" row: two more holes hole_dy mm further down, toward
//     the ribbon edge.
hole_dx            = 21;    // horizontal spacing between L and R holes
hole_dy            = 12.5;  // vertical spacing between top and bottom rows
hole_top_inset     = 2.0;   // inset from far-from-ribbon edge to top row

// ---------------- HOLDER STRUCTURE ----------------
wall_t             = 2.5;   // wall around PCB pocket
front_plate_t      = 6.0;   // material in front of the DEEPEST part of the
                            //   pocket (connector zone).  Set by the "don't
                            //   make the whole thing too thick" constraint:
                            //   6 mm keeps the plate slim while still giving
                            //   ~9 mm of material behind the chips (where
                            //   the four M2 screws actually bite), which is
                            //   plenty for M2×6 to M2×8 self-tap screws.
pocket_clear       = 0.4;   // extra depth+width slop in PCB pocket

// ---------------- FASTENERS ----------------
// Self-tap screw holes are STEPPED: a clearance-sized bore for most of
// the length (so the screw shank drops in freely) and a smaller pilot
// diameter only at the tip (where the threads actually bite into
// plastic).  This is the standard practice for self-tap into plastic —
// a straight pilot-through-full-length forces the threads to cut the
// entire depth of the hole, which is what makes screws physically hard
// to drive.  Stepped holes let you sink an M2×8 with a screwdriver in
// one easy turn.
m2_clearance      = 2.5;   // clearance hole for M2 shank (bumped from 2.3
                           //   to 2.5 for FDM print tolerance — a 2.3 mm
                           //   hole prints ~2.1 mm after shrinkage / wall
                           //   squish, and an M2 shank is already ~2.0 mm,
                           //   so there's almost no slop.  2.5 mm gives
                           //   the shank real drop-through clearance.)
m2_pilot          = 1.9;   // pilot diameter for M2 SOCKET HEAD CAP screw
                           //   form-tapping into PLA on a Bambu X1C.
                           //   A cap screw has no cutting flute, so it
                           //   *displaces* plastic instead of cutting it.
                           //   Sizing math: M2 major ⌀ = 2.0 mm, minor
                           //   ⌀ ≈ 1.55 mm.  We want the printed hole to
                           //   land around ⌀1.75 mm so the screw displaces
                           //   ~0.12 mm radially per side — tight enough
                           //   to grip, loose enough to drive with a
                           //   1.5 mm hex key without stripping the hex.
                           //   X1C PLA horizontal holes print ~0.15 mm
                           //   undersize, so CAD value 1.9 → printed 1.75.
m2_thread_engage  = 11.0;  // length (mm) of the PILOT-sized section at
                           //   the FRONT of the bore.  With plate depth
                           //   ≈ 13.2 mm and thread_engage = 11, only the
                           //   back ~2.2 mm is wide clearance (for screw
                           //   alignment lead-in); the remaining 11 mm
                           //   is form-tap pilot.  A 10 mm screw enters
                           //   with ~2 mm of head standoff (PCB in
                           //   pocket) and reaches the pilot zone almost
                           //   immediately, giving ~6 mm of real thread
                           //   engagement — plenty for M2 in PLA.
                           //   WARNING: if you shorten the screw or
                           //   thicken the front plate, recompute this.
                           //   The screw TIP must land inside the pilot
                           //   zone; otherwise the screw spins freely in
                           //   clearance and never bites.
use_self_tap    = true;  // true = stepped clearance+pilot hole (screw
                         //   threads into plastic only at the tip)
                         // false = straight clearance hole all the way
                         //   through (use M2 nuts on the front face)
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

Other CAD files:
outputs/30th April 2026 - mesh sequence [20260430 manipulation]/mesh_0404.obj
outputs/30th April 2026 - mesh sequence [20260430 manipulation]/mesh_0003.obj
outputs/30th April 2026 - mesh sequence [20260430 manipulation]/mesh_0487.obj
outputs/30th April 2026 - mesh sequence [20260430 manipulation]/mesh_0236.obj
cad/dual_picam3_holder.stl
cad/dual_picam3_holder_v2.stl
outputs/30th April 2026 - mesh sequence [20260430 manipulation]/mesh_0000.obj
outputs/30th April 2026 - mesh sequence [20260430 manipulation]/mesh_0001.obj
outputs/30th April 2026 - mesh sequence [20260430 manipulation]/mesh_0002.obj
outputs/30th April 2026 - mesh sequence [20260430 manipulation]/mesh_0004.obj
outputs/30th April 2026 - mesh sequence [20260430 manipulation]/mesh_0005.obj
outputs/30th April 2026 - mesh sequence [20260430 manipulation]/mesh_0006.obj
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

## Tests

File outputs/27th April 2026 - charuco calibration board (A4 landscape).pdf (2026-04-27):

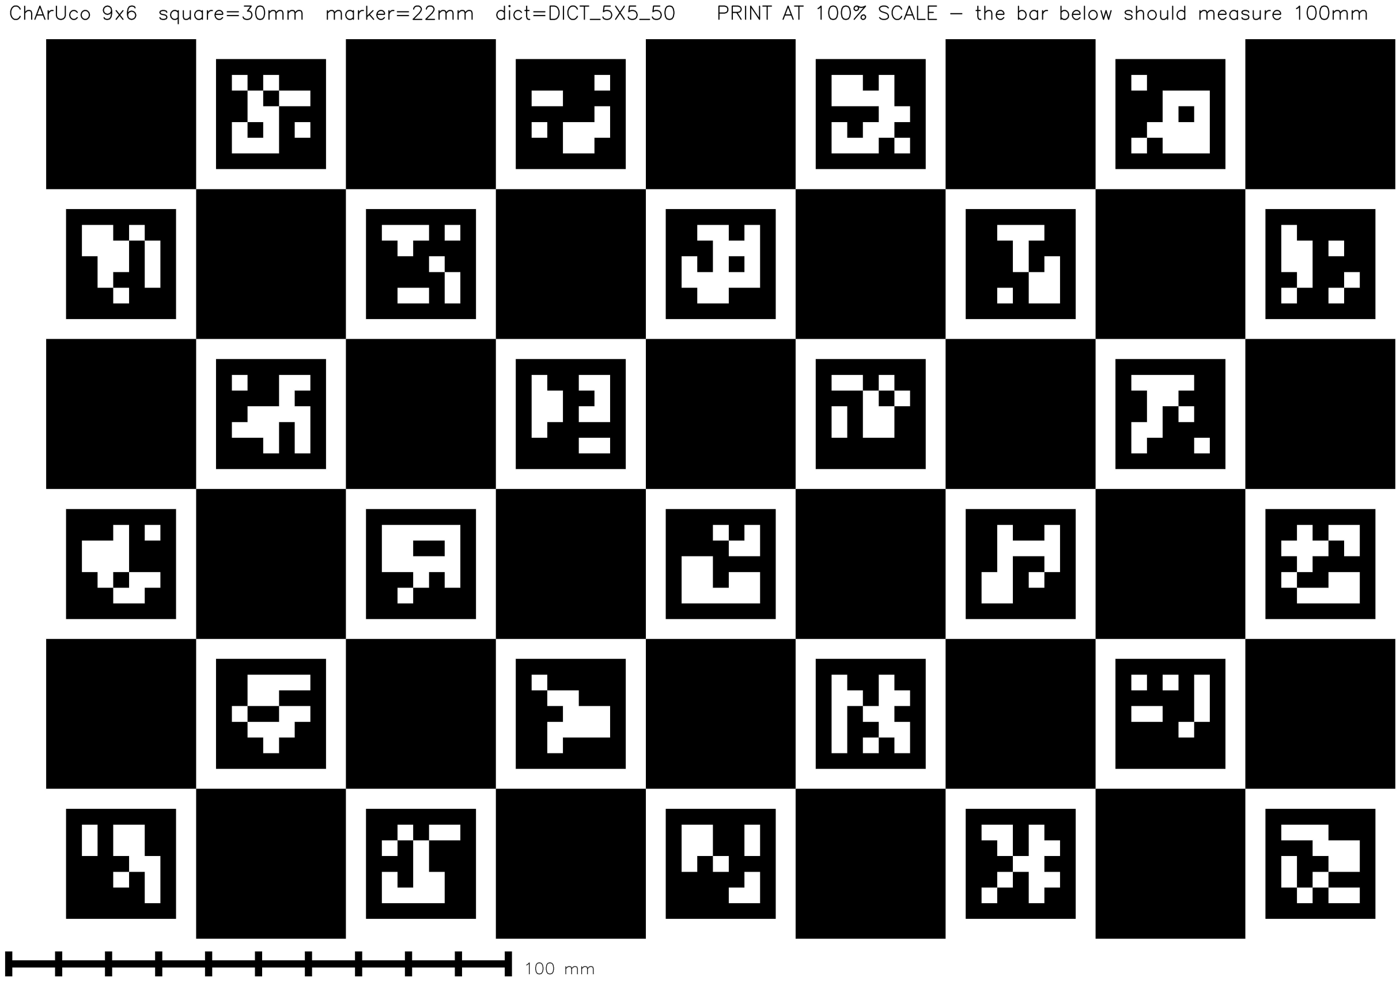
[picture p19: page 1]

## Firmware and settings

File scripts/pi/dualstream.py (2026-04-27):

"""Dual Pi Cam 3 Wide live preview + recording server, with sensor-mode switching.

Runs an HTTP server on :8080 that:
  - Streams MJPEG previews of both cameras at /cam0 and /cam1.
  - Exposes a small HTML UI with buttons to start/stop H.264 recording.
  - Lets you switch the underlying SENSOR mode (1536x864 cropped /
    2304x1296 binned full-FOV / 4608x2592 full-sensor full-FOV) so you can
    visually compare FOVs before committing to one for capture.

Why sensor mode matters: by default, picamera2 picks the smallest sensor
mode that can produce the requested main output (1280x720 here), which on
the IMX708 is the 1536x864 CENTRE-CROPPED mode - effectively ~75 deg HFOV
on the wide variant. The 2304x1296 binned mode reads the full sensor and
gives the camera's native ~102 deg HFOV at the same 1280x720 main output.

Caveats:
  - Switching mode changes FOV AND the intrinsic camera matrix, so the
    stereo calibration must be re-run after picking the final mode.
  - The 4608x2592 mode caps at ~14 fps; can't sustain 30 fps recording.
    The 2304x1296 mode caps at ~56 fps and IS full-FOV - the sweet spot.
"""

import io
import signal
import sys
import time
from datetime import datetime
from http.server import HTTPServer, BaseHTTPRequestHandler
from socketserver import ThreadingMixIn
from threading import Condition, Lock
from urllib.parse import urlparse, parse_qs

from libcamera import Transform
from picamera2 import Picamera2
from picamera2.encoders import H264Encoder, MJPEGEncoder
from picamera2.outputs import FileOutput

PREVIEW_SIZE = (1280, 720)
TARGET_FPS = 30   # locked across all sensor modes that can sustain it; the
                  # 4608x2592 mode can't (caps at ~14 fps) and falls back to
                  # the mode's max.


class StreamingOutput(io.BufferedIOBase):
    def __init__(self):
        self.frame = None
        self.condition = Condition()

    def write(self, buf):
        with self.condition:
            self.frame = buf
            self.condition.notify_all()


# ---------------------------------------------------------------------------
# Sensor-mode discovery + camera (re)configuration
# ---------------------------------------------------------------------------
def discover_modes(cam):
    """Return list of (w, h, max_fps, full_fov) for the camera, dedup'd, sorted."""
    sensor_w = max(m["size"][0] for m in cam.sensor_modes)
    sensor_h = max(m["size"][1] for m in cam.sensor_modes)
    seen = {}
    for m in cam.sensor_modes:
        w, h = m["size"]
        crop = m.get("crop_limits", (0, 0, sensor_w, sensor_h))
        full_fov = (crop[0] == 0 and crop[1] == 0
                    and crop[2] == sensor_w and crop[3] == sensor_h)
        # If we've seen this (w, h) already, keep the entry with the higher fps.
        prev = seen.get((w, h))
        fps = m.get("fps", 0.0)
        if prev is None or fps > prev[2]:
            seen[(w, h)] = (w, h, fps, full_fov)
    return sorted(seen.values(), key=lambda x: x[0] * x[1])


def actual_fps_for_mode(raw_size):
    """Pick the recording fps: TARGET_FPS if the mode supports it, else the mode max."""
    mode_max = next((fps for (w, h, fps, _) in modes if (w, h) == raw_size), TARGET_FPS)
    return min(TARGET_FPS, int(mode_max))


def configure_for_mode(cam, raw_size):
    """Configure cam for video with the given raw sensor size + locked frame rate.

    Returns the fps the camera will actually run at (TARGET_FPS or mode max).
    """
    fps = actual_fps_for_mode(raw_size)
    frame_duration_us = int(round(1_000_000 / fps))
    cfg = cam.create_video_configuration(
        main={"size": PREVIEW_SIZE},
        lores={"size": PREVIEW_SIZE},
        raw={"size": raw_size},
        controls={"FrameDurationLimits": (frame_duration_us, frame_duration_us)},
        transform=Transform(hflip=True, vflip=True),
    )
    cam.configure(cfg)
    return fps


def start_preview(cam, output):
    cam.start_recording(MJPEGEncoder(), FileOutput(output))


# ---------------------------------------------------------------------------
# State
# ---------------------------------------------------------------------------
output0 = StreamingOutput()
output1 = StreamingOutput()
state_lock = Lock()
recording = False
rec_files = []
rec_encs = {}

picam0 = Picamera2(1)
picam1 = Picamera2(0)

modes = discover_modes(picam0)
# Default: largest mode that still hits >=30 fps. For IMX708 Wide that's the
# 2304x1296 binned full-FOV mode (~56 fps cap). 4608x2592 caps at ~14 fps so
# it can't sustain 30 fps recording.
candidates_30fps = [m for m in modes if m[2] >= 30.0]
default_mode = max(candidates_30fps, key=lambda m: m[0] * m[1]) if candidates_30fps else modes[-1]
current_raw = (default_mode[0], default_mode[1])

print("Available sensor modes (* = current default):")
for w, h, fps, full in modes:
    flag = "*" if (w, h) == current_raw else " "
    note = "FULL FOV" if full else "cropped FOV"
    will_record_at = min(TARGET_FPS, int(fps))
    print(f"  {flag} {w:4d} x {h:<4d}   max {fps:6.2f} fps   "
          f"records at {will_record_at} fps   {note}")

active_fps = configure_for_mode(picam0, current_raw)
start_preview(picam0, output0)
time.sleep(2)
configure_for_mode(picam1, current_raw)
start_preview(picam1, output1)


# ---------------------------------------------------------------------------
# HTML UI
# ---------------------------------------------------------------------------
HTML_PAGE = """
<!DOCTYPE html>
<html>
<head>
<title>Pi 5 Dual Camera</title>
<style>
  body { background:#111; color:#fff; font-family:sans-serif; margin:0; padding:0;
         display:flex; flex-direction:column; align-items:center; min-height:100vh; }
  h1 { margin:16px 0 8px; }
  .row { display:flex; gap:8px; flex-wrap:wrap; justify-content:center;
         align-items:center; margin:6px 0; }
  button { padding:10px 14px; font-size:14px; border:none; border-radius:6px;
           cursor:pointer; font-family:inherit; }
  .rec      { background:#c00; color:#fff; } .rec:hover      { background:#e00; }
  .stop-btn { background:#555; color:#fff; } .stop-btn:hover { background:#777; }
  .mode     { background:#246; color:#fff; }
  .mode:hover { background:#357; }
  .mode.active { background:#4a8; outline:2px solid #fff; }
  #status { color:#aaf; font-family:monospace; margin-top:6px; min-height:1.2em; }
  .warn   { color:#fb6; font-size:12px; margin:4px 0; max-width:740px; text-align:center; }
  .container { display:flex; gap:16px; flex-wrap:wrap; justify-content:center; padding:12px; }
  .cam img { border-radius:6px; max-width:90vw; width:640px; }
  .cam p { color:#aaa; margin:6px 0; }
</style>
</head>
<body>
<h1>Dual Camera Stream</h1>
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

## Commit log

2026-04-25 initial object detection from both different cameras
    - process.py: stitch the two head-mounted Pi Cam 3 streams (cam0/cam1, 24 deg toe-out)
    into a single panorama video via SIFT + RANSAC homography estimated once on a
    mid-clip frame and reused for all frames.
    - hands.py: MediaPipe HandLandmarker (Tasks API) sanity check — annotates 21
    keypoints per hand on each clip; ~99.6% / 93.1% detection rate on cam0 / cam1.
    - CAD: dual_picam3_holder (v1, v2) sources + STL/3MF exports for the head mount.
    - Reference still captures from each camera kept as test fixtures.
    [dual_picam3_holder.3mf, dual_picam3_holder.scad, dual_picam3_holder.stl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]
2026-04-25 organise repo into inputs/ and outputs/ with readable dated filenames
    - inputs/ holds tracked test material (reference photos, 15-second test clips
    extracted from the 4-min recordings) named with their capture date, e.g.
    '24th April 2026 - photo cam0.jpg'.
    - outputs/ holds tracked generated artifacts named with their generation date,
    e.g. '25th April 2026 - cam0 hands annotated.mp4'.
    - dated.py: today_pretty() helper used by process.py and hands.py so each run
    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
2026-04-25 hand detection on first minute of each camera
    Detection rates over 1801 frames per stream:
    - cam0: 1483/1801 = 82.3% (down from 99.6% on the close-grip clip)
    - cam1: 1689/1801 = 93.8% (similar to 93.1% on the close-grip clip)
    The cam0 drop is the new-info finding: when the hand is mid-air or in motion
    between manipulations (rather than close to the lens gripping something), the
    detector either drops or hallucinates. Sample frames committed to illustrate:
    - 10s motion blur: hand is a blur, confidence drops to 0.67 but tracking holds.
    - 30s topology failure: only one skeleton detected, but it spans across both
    hands - palm on one hand, fingers on the other. Confidence 1.00, topology
    wrong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
2026-04-27 generate ChArUco calibration board sized for the Pi Cam 3 rig
    Board geometry chosen for 1280x720 capture, ~75 deg HFOV, 30-80cm working
    distance:
    - 9x6 squares, 30mm each (270x180mm board, fits A4 landscape).
    - ~42 px per square at 60cm capture, ~30 px at 80cm - comfortably above the
    sub-pixel corner-detection floor.
    - 22mm ArUco markers (DICT_5X5_50) in alternating squares; 27 markers, 40
    inner ChArUco corners.
    - 5x5 dictionary chosen over 4x4 for stronger error correction.
    PDF rendered at 600 DPI with a 100mm scale bar so print fidelity can be
    verified with a ruler. Print at 100% scale (no fit-to-page).
    Generator script committed so the board is reproducible and any geometry
    tweaks (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
2026-04-27 stereo calibration (stage 3): script, capture footage, recovered geometry
    calibrate.py samples ChArUco frame pairs from a tripod-held capture, runs per-camera
    intrinsics + stereo extrinsics, then rectifies with alpha=1 to preserve the full FOV
    (alpha=0 cropped the top of the frame, where hands held high need to be visible).
    Calibration on the 27th April capture: 71/79 usable pairs, sub-pixel reprojection
    error (cam1 0.24 px / cam0 0.27 px / stereo 0.26 px). Recovered toe-out 18.9 deg
    (designed 24 - bracket print tolerance) and baseline 41.1 mm. Sanity image confirms
    scanline alignment.
2026-04-27 sparse 3D hand triangulation (stage 4): pipeline, results, trajectory plot
    triangulate.py rectifies both streams via the calibration remap tables, runs
    MediaPipe HandLandmarker on each view independently, pairs left/right hands by
    wrist-row proximity (the epipolar constraint after rectification), then
    triangulatePoints with P1/P2 to get metric 3D landmarks in the left rectified
    frame. A wrist-Z bound of [10cm, 200cm] catches wrong-hand pairings the row
    check lets through. Hand slots are sorted by left-view wrist X for frame-to-
    frame stability. Per-frame (N, 2, 21, 3) landmarks dump to .npz alongside the
    annotated SBS video.
    inspect_3d.py loads the .npz and plots wrist depth + thumb-index p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
2026-04-27 update README and CLAUDE.md: stages 3 and 4 done, recovered geometry, new files
    README: pipeline-plan table marks stages 3 and 4 as Done with stage 5 (SAM 2)
    as Next. New sections describe the calibration and triangulation pipelines with
    their result tables. Hardware section now distinguishes designed 24 deg toe-out
    from calibrated 18.9 deg, noting that all math should use the calibrated value.
    CLAUDE.md: documents the cam0=right / cam1=left convention used everywhere; adds
    architecture notes for calibrate.py and triangulate.py, including why
    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
2026-04-27 stage 8 phase 0+1: WiLoR + stereo dexterous-hand pipeline (env, sanity)
    The MediaPipe stereo pipeline gives 21 sparse points per hand, but the captured
    dataset is for robot-manipulation imitation across many gripper types
    (parallel-jaw, 3-finger, anthropomorphic). The dataset must be richer than any
    specific gripper, so we're moving to MANO-producing models. WiLoR (CVPR 2025)
    is the chosen frontend: end-to-end, single-stage, MPS-friendly, no detectron2.
    Phase 0 (env): Python 3.10 (Homebrew) + .venv-hamer with PyTorch+MPS, the
    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
    [27th April 2026 - wilor sanity hand0.obj]
2026-04-27 stage 8 phase 2 + minimal phase 3: per-view WiLoR + stereo wrist triangulation
    This is the first WiLoR run that actually uses the dual-camera setup. Per
    frame pair:
    1. YOLO detect on each raw view (CPU - ultralytics MPS bug for Pose models).
    2. WiLoR forward pass per detected hand per view (MPS, ~0.9 s warm).
    3. Project each wrist 2D into rectified space via cv2.undistortPoints +
    R1/R2/P1/P2 from calibrate.py's .npz.
    4. Match left/right hand detections by rectified wrist-row proximity.
    5. Triangulate matched wrists with cv2.triangulatePoints(P1, P2, ...) for
    metric 3D wrist depth - the thing WiLoR alone cannot give us
    (it's monocular and scale-ambiguous).
    6. Sanity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
2026-04-27 stage 8: wide-FOV captures, recalibration, CLI args + 60-s perf trace
    - dualstream.py: discover sensor modes via picamera2 cam.sensor_modes,
    expose them as buttons in the live HTML UI, lock to 30 fps via
    FrameDurationLimits. Default mode is 2304x1296 (full IMX708 sensor,
    ~100° HFOV) instead of the cropped 1536x864 (~75°) we were on before.
    - calibrate.py: TAG=" wide" so wide-FOV recalibration writes alongside
    the original narrow calibration. Result: 0.37/0.42/0.61 px rms,
    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
2026-04-27 restructure root: scripts/ + cad/ + raw/ + models/ for navigability
    The repo root had grown to ~30 mixed files (scripts, CAD, raw camera
    recordings, gitignored model weights). Move them into purpose-named
    subdirs so the root holds just docs, data dirs, and envs.
    scripts/ all pipeline entry points (run from repo root)
    cad/ head-mount OpenSCAD source + STL/3MF exports
    raw/ gitignored - local-only raw cam mp4 + h264 streams
    models/ gitignored - re-downloadable weights (hand_landmarker.task)
    Code adjustments to keep everything working post-move:
    - scripts/{wilor_sanity,wilor_stereo_demo}.py: PROJECT_ROOT now
    Path(__file__).resolve().parents[1]. Dropped the dated.py sys.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
    [dual_picam3_holder.3mf, dual_picam3_holder.scad, dual_picam3_holder.stl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]
2026-04-27 stage 8 phase 3 (full): first triangulation-based mesh fusion experiment
    Two scripts that take stage 8 from per-view monocular WiLoR up to a fully
    stereo-fused MANO mesh, plus PLAN.md fleshed out with the algorithm, output
    schema, validation criteria, and roadmap for 3.4/3.5.
    scripts/wilor_ar_overlay.py — per-view monocular AR overlay (the baseline
    this experiment is compared against). Fits a weak-perspective affine from
    WiLoR's pred_keypoints_3d.xy to pred_keypoints_2d to project all 778 MANO
    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
2026-04-27 stage 8 phase 3 (anchored): monocular pose + stereo depth, replaces full Umeyama as canonical
    Per the discussion in the previous commit's negative result: the 7-DOF
    Umeyama refit gave us cross-view 3D consistency at the cost of WiLoR's
    per-view 2D accuracy (median 10 px reproj, 27 px tail). The fix is to
    let WiLoR be good at what it was trained for (monocular 2D + relative
    3D) and use stereo only for the one thing it can uniquely give us:
    absolute metric scale.
    Algorithm — per matched-hand pair, per view:
    1. WiLoR forward pass -> pred_vertices, pred_keypoints_3d (MANO local
    frame), pred_keypoints_2d_full (real-image pixels).
    2. cv2.solvePnP(SQPNP) -> (R, t) so the mesh in the real cam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
2026-04-30 scripts/: role-based reorg, CUDA/MPS portability, --bench, doc refresh
    Repo had grown to 16 flat scripts mixing canonical pipeline, debug
    viewers, one-shot setup, and historical experiments. Segregated into
    six subdirs by role:
    scripts/
    _lib/ shared imports (dated, device, wilor_setup)
    pi/ on-Pi capture
    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
2026-04-30 stage 8 phase 4 prep: 30 April recalibration + ArUco table-frame anchor
    Old "27 April wide" calibration was actually shot on the narrow sensor
    mode despite the filename tag — fx ≈ 803 px (~76° HFOV) instead of the
    ~545 px (~99° HFOV) the wide mode should give. Triangulated objects came
    out 14% smaller than physical (an 80 mm marker measured as ~67 mm) and
    the anchored canonical pipeline's stereo-vs-monocular wrist scale ratio
    sat at 0.95 / 0.88 instead of ~1.0.
    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
2026-04-30 stage 8 phase 4: table-frame inspection viz + anchor robustness
    scripts/viz/inspect_anchored.py: quick-look visualisation that
    combines the canonical pipeline's wrist_3d_world with the anchor's
    T_world_to_table to show:
    - top-down trajectory (table X-Y) with the marker at (0, 0)
    - side view (X-Z) — height profile against table surface
    - wrist Z over time
    - presence strip showing per-slot detection + anchor-only frames
    Two fixes in 09_anchor_table.py while building the viz:
    1. Saved R_world_to_table / t_world_to_table were in the wrong
    direction. solvePnP returns (R, t) with X_camera = R · X_marker
    + t (marker→camera), but the saved fields had been computed as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
2026-04-30 canonical: save MANO θ + β; first real manipulation clip end-to-end
    08_wilor_canonical.py now extracts pred_mano_params from WiLoR's output
    and saves three new fields per frame per slot:
    mano_global_orient_R (N, 2, 1, 3, 3) wrist rotation in MANO local frame
    mano_hand_pose_R (N, 2, 15, 3, 3) 15 finger joints (MCP/PIP/DIP × 5)
    mano_betas (N, 2, 10) person-shape coefficients
    Saved as 3×3 rotation matrices for fidelity (WiLoR runs MANO with
    pose2rot=False internally, so these are the model's native form). The
    dataset-export step converts to the standard axis-angle θ format.
    Mirroring fix for left hands. WiLoR's ViTDetDataset flips left-hand
    input crop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
2026-04-30 phase 5: dataset export — table-frame, retargeting-ready .npz
    scripts/pipeline/10_export_dataset.py consumes the canonical pipeline
    output + the table-anchor output and writes a single self-contained
    .npz with everything in **table frame** (Z=0 = table surface, +Z up).
    This is the first artifact downstream code (a Blender importer, a
    PAROL6 retargeter, an imitation-learning policy) can consume directly.
    Schema (saved as schema_version="1.0"):
    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
2026-04-30 phase 5 viz: OBJ mesh-sequence export for Blender / Maya / etc.
    scripts/viz/export_obj_sequence.py consumes the Phase 5 dataset .npz
    and writes a directory of plain-text Wavefront OBJ files — one per
    frame — that any 3D modelling software can open without extra
    dependencies. This is the visualisation companion to the .npz dataset.
    Output layout:
    outputs/<date> - mesh sequence [<tag>]/
    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
    [mesh_0000.obj, mesh_0001.obj, mesh_0002.obj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]
2026-04-30 add CONCEPTS.md — pipeline concepts in Q&A form
    Six explainer sections captured during development, covering the
    foundations needed to understand and extend the pipeline:
    1. CV models in use + full data flow + the two non-obvious tricks
    2. The blue-glove rendering
    3. MANO vs WiLoR
    4. θ / β storage, units, reference frames
    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
2026-04-30 phase 5 viz: NiceGUI web viewer for the OBJ mesh sequence
    scripts/viz/web_viewer.py — browser-based 3D viewer that loads the OBJ
    mesh sequence directory from scripts/viz/export_obj_sequence.py and
    plays it back with timeline scrubbing + play/pause.
    Architecture cribbed from Jepson2k/Waldo-Commander
    (services/urdf_scene/) — Python server holds state, NiceGUI pushes
    Three.js commands to the browser, browser does the WebGL rendering.
    Step 1 of the build sequence in VIEWER_HANDOFF.md:
    - Static scene helpers: table plane (Z=0) + ArUco marker outline at
    origin + small RGB world axes.
    - Per-frame hand mesh swapped in/out (per slot) on slider change.
    - Auto-play via ui.timer.
    - Sin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
2026-04-30 viewer: Z-up camera + table-frame axis colors + 15 fps default
    Two fixes from feedback on the first cut:
    (1) Axis convention. Was rotating the data into Three.js's Y-up at
    STL-export time then drawing axes in viewer coords; user observed
    that this read as "red+blue lie on the table base, green points
    up" — which is correct visually, but uses the wrong colour for
    "up" if you're thinking in table-frame X/Y/Z.
    New approach: tell Three.js the world is Z-up via the camera's
    up vector (`scene.move_camera(..., up_x=0, up_y=0, up_z=1)`),
    keep the data in its native table frame (no rotation), and draw
    axes with the standard X=red, Y=green, Z=blue convention. Now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
2026-04-30 stage 9 phase 1+2: SAM2 object segmentation pipeline (click UI + video propagation)
    First two scripts of the markerless object-tracking pipeline that runs on
    top of the existing canonical pipeline (table frame + hand mesh).
    11_click_objects.py — interactive click UI: one positive click per
    object in the LEFT rectified frame, label typed in the terminal,
    right-view click auto-recovered by NCC template matching along the
    rectified epipolar row (±5 px slack for residual rectification
    error). CPU-only; .venv. Output: outputs/<date> - object clicks
    [<tag>].json.
    12_segment_objects.py — SAM2.1-large video predictor on each rectified
    view independently, seeded fro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
2026-04-30 11_click_objects: display raw frames by default to dodge alpha=1 rectification warp
    The saved stereo calibration uses alpha=1 to preserve the full source
    FOV (the rest of the pipeline depends on this), but on the wide-FOV
    cameras (~100° HFOV) the rectified image is a small curved valid region
    surrounded by black ("two small spheres" — see play_stereo.py for the
    canonical description). That made the click UI unusable: most of the
    frame was black or warped, with no objects in clear view to click on.
    Fix: display the RAW frames for clicking by default. Internally we still
    need rectified clicks (SAM2 in 12_segment_objects.py is fed rectified
    frames + a rectified seed click), so each raw clic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
2026-04-30 12_segment_objects: render preview on raw frames (mask warped from rect → raw)
    Issue: the SBS preview was on alpha=1 rectified frames, which compress
    the scene into a small curved valid region surrounded by black on
    wide-FOV cameras — same "two small spheres" problem as the click UI,
    just downstream this time. The phone mask was correct but unreadable.
    Fix: render the SBS overlay on the RAW (un-rectified) source frames.
    Each rectified-space SAM2 mask is forward-warped into raw image space
    via a per-pixel inverse rectification map, computed once per view by
    running cv2.undistortPoints on every (xr, yr) in the raw grid (one-time
    cost, then cv2.remap per frame).
    write_preview_video now ta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
2026-04-30 experiment: SAM2 auto-init + video propagation hybrid
    scripts/experiments/sam2_auto_to_video_demo.py — runs the automatic
    mask generator on frame 0 of the LEFT raw video, filters the result
    (area + predicted_iou), then seeds each kept mask into the video
    predictor via add_new_mask and propagates across the rest of the clip.
    The point: get auto-init's "no clicking required" plus the video
    predictor's stable identity through occlusion, in one script.
    Defaults:
    --max-objects 15 (memory attention scales linearly; ~5 fps on L4)
    --min-area-frac 0.001 (drops masks <920 px on 1280x720 — noise)
    --max-area-frac 0.30 (drops huge background / table-surface masks)
    --points-per-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
